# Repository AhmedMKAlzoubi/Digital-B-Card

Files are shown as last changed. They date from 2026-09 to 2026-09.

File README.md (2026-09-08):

# Digital Business Card (Digital-B-Card)

An ESP32-C3 based digital business card / badge with an e-paper display and NFC tap-to-share, designed as a custom PCB in a compact card/badge form factor.

## Overview

This project is a self-contained electronic business card. It combines a low-power microcontroller, an e-paper display for a persistent, battery-friendly visual, and an NFC tag for one-tap contact sharing on any NFC-enabled phone. The board is designed to fit inside a 3D-printed badge enclosure.

## Key Features

- **MCU:** ESP32-C3-MINI-1-N4 (RISC-V, Wi-Fi / BLE, native USB) for control logic and OTA wireless updates.
- **Display:** 2.66" e-paper panel (GDEM0266T71WT) driven by the SSD1680 controller — ultra-low power, always-on readability.
- **NFC:** NXP NT3H2111 NTAG I²C tag + custom 8-turn PCB antenna for tap-to-share contact info with any NFC-enabled phone.
- **Power:** MCP73871-2CC power-path LiPo charger + MAX17048 fuel gauge + AP2112K-3.3 LDO — USB-C charging with seamless battery monitoring.
- **Custom PCB:** Designed in KiCad, fabricated as a 2-layer, single-sided 100 × 60 mm board.
- **Custom Case:** 3D-modeled badge enclosure (FreeCAD) with an optional 3D nameplate.

## Repository Structure

| Folder / File | Description |
|---|---|
| `PCB-Schem/` | KiCad schematic (`.kicad_sch`) and PCB layout (`.kicad_pcb`) source files. |
| `Gerber/` | Fabrication-ready Gerber files, drill files, job file, and `gerber.7z` for direct upload to a PCB manufacturer. |
| `BOM/` | Bill of materials (`digital card-BOM.csv`). |
| `datasheets/` | Component datasheets and reference documents (see [Datasheets & Spec Sheets](#datasheets--spec-sheets) below). |
| `Case/` | FreeCAD badge case models (`Digital_Card_Case_3_BADGE.FCStd`), a backup revision, and a 3D nameplate (`case-nameplate.glb`). |
| `Digital_C-Case_Viewer.html` | Standalone browser-based 3D viewer for the case / nameplate model. |
| `DOC/` | Full project report (`Digital_Business_Card_Report.zip`) covering design decisions, testing, and build notes. |

---

## Specification Sheet

> Rev A — 2026-08-24. Values are marked **[V]** verified against a datasheet/layout/CAD, **[E]** estimated, or **[TBC]** to be confirmed on hardware.

### At a Glance

| Parameter | Value |
|---|---|
| Function | E-paper display with NFC tap-to-share and Wi-Fi / BLE connectivity |
| Modes | Desk nameplate / event badge / tap-to-share card (firmware-selected) |
| Outer dimensions | 104.6 × 69.6 × 11.1 mm **[V]** |
| Mass, assembled | ≈ 68 g **[E]** |
| Power | 1S Li-Po, USB-C rechargeable |
| Enclosure | Two-part 3D print, M2 screws |
| MCU | ESP32-C3-MINI-1-N4 (RISC-V, Wi-Fi + BLE, native USB) |
| Display | 2.66" e-paper, 152 × 296 px, SSD1680 driver (GDEM0266T71WT) |
| Connectivity | NFC (NT3H2111 + custom PCB antenna), Wi-Fi, BLE |
| Charging | USB-C, MCP73871-2CC power-path Li-Po charge management |
| Regulation | AP2112K-3.3 LDO |
| Fuel gauge | MAX17048 |
| Battery | 1S Li-Po, 500 mAh (Uxney 503035, 200–600 mAh range supported) |
| Design tool | KiCad |
| Manufacturing | JLCPCB, 2-layer, full SMT assembly |

### PCB Mechanical

| Parameter | Value |
|---|---|
| Outline | 100.0 × 60.0 mm **[V]** |
| Thickness | 1.6 mm **[V]** |
| Layers | 2 (F.Cu, B.Cu) **[V]** |
| Assembly | Single-sided — all components on B.Cu **[V]** |
| Mounting holes | 4 × Ø2.2 mm NPTH for M2, 2.75 mm from each corner **[V]** |
| Min track width | 0.25 mm signal / 0.40 mm power **[V]** |
| Min clearance | 0.20 mm (0.50 mm on HV class) **[V]** |
| Via / drill | 0.6 / 0.3 mm **[V]** |
| Surface finish | ENIG recommended |
| Placements | 59 across 27 orderable line items **[V]** |

### Enclosure

| Parameter | Value |
|---|---|
| Outer | 104.6 × 69.6 × 11.1 mm **[V]** |
| Wall / floor thickness | 2.0 mm **[V]** |
| PCB fit clearance | 0.3 mm per side **[V]** (may open to 0.4–0.5 mm **[TBC]**) |
| Split line | z = +1.6 mm — tray below, cover above **[V]** |
| Internal cavity | 100.6 × 65.6 × 5.5 mm deep **[V]** |
| Board support | 4 × Ø4.5 mm bosses with Ø1.7 mm pilot holes **[V]** |
| Fasteners | 4 × M2 self-tapping; nylon in the two holes nearest the NFC coil |
| USB-C opening | 12.6 × 6.2 mm **[V]** |
| Button access | 2 × Ø2.0 mm through tray floor **[V]** |

### Display

| Parameter | Value |
|---|---|
| Part | GDEM0266T71WT (Good Display) |
| Technology | E-paper, monochrome, bistable — zero power to hold image |
| Controller | SSD1680 (Solomon Systech) |
| Diagonal | 2.66" |
| Resolution | 152 × 296 px **[V]** |
| Active area | 30.704 × 60.088 mm **[V]** |
| Interface | 4-wire SPI, BS1 strapped low **[V]** |
| Connector | 24-pin 0.5 mm FPC, 14 mm tail **[V]** |
| Typical operating current | 4.5 mA **[V]** |
| Peak refresh current | 40 mA typ / 60 mA max **[V]** |

### Wireless

| Parameter | Value |
|---|---|
| MCU module | ESP32-C3-MINI-1-N4 (Espressif), RF pre-certified |
| Core | 32-bit RISC-V single core |
| Flash | 4 MB |
| Wi-Fi | 802.11 b/g/n, 2.4 GHz |
| Bluetooth | BLE 5 |
| Wi-Fi/BLE Antenna | Integrated module PCB antenna, overhanging board edge per Espressif guidance **[V]** |
| USB | Native USB (GPIO18/19) — programming and debug, no UART bridge |

### NFC

| Parameter | Value |
|---|---|
| Tag IC | NT3H2111W0FHKH (NXP NTAG I²C plus) |
| Standard | NFC Forum Type 2, 13.56 MHz |
| Host interface | I²C |
| Antenna | Custom PCB coil on F.Cu — 8 turns, 0.6 mm trace, 0.3 mm gap **[V]** |
| Coil area | 15 × 50 mm **[V]** |
| Coil inductance | ≈ 1.93 µH **[E]** |
| Chip capacitance | 50 pF **[V]** (datasheet §13.1) |
| Tuning capacitor | 22 pF C0G/NP0 **[V]** |
| Field-detect | FD → GPIO3, deep-sleep wake on tap **[V]** |
| Read range | **[TBC]** — C14 is the tuning point |

### Power

| Parameter | Value |
|---|---|
| Battery chemistry | Lithium polymer, 1 cell |
| Capacity | 500 mAh (200–600 mAh range supported) |
| Nominal / max voltage | 3.7 V / 4.2 V |
| Cell | Uxney 503035, 35 × 30 × 5 mm, integrated protection |
| Connector | JST-PH 2.0 mm, S2B-PH-SM4-TB horizontal SMT **[V]** |
| Regulation output | 3.3 V (AP2112K LDO, 600 mA rated) |
| LDO input source | Charger SYS/OUT rail — **not** VBAT |
| Charge IC | MCP73871-2CC, power-path topology |
| Charge voltage | 4.20 V **[V]** |
| Input current limit | 500 mA **[V]** |
| Charge current | ≈ 303 mA **[E]** |
| Termination current | ≈ 42 mA **[E]** |
| Safety timer | 6 h **[V]** |
| Worst-case dissipation | ≈ 0.4 W **[E]** |
| Fuel gauge | MAX17048, ModelGauge, 3 µA operating, I²C, ALRT → GPIO4 wake |

### Current Budget

| State | Estimate | Note |
|---|---|---|
| Deep sleep | ≈ 10–20 µA | MCU deep sleep + gauge 3 µA + leakage |
| Display holding image | 0 µA | Bistable — no power to retain |
| Display refresh | 40–60 mA for a few seconds | Panel datasheet §6.2 |
| Wi-Fi transmit | up to ≈ 350 mA peak | ESP32-C3 typical |
| NFC tap (harvested) | Field-powered | Tag responds without waking MCU |

### GPIO Pin Map

| GPIO | Net | Notes |
|---|---|---|
| 0 | I2C SDA | Shared bus — NFC + fuel gauge |
| 1 | I2C SCL | Shared bus |
| 2 | EPD RST | Strapping pin, 10 kΩ pull-up, idles high |
| 3 | NFC FD | Field detect; deep-sleep wake on tap (RTC-capable) |
| 4 | FUELGAUGE ALERT | MAX17048 ALRT; deep-sleep wake (RTC-capable) |
| 5 | EPD BUSY | Input |
| 6 | EPDCLK | E-paper SPI clock |
| 7 | EPDDATA | E-paper SPI data |
| 8 | STATUS LED | Strapping — must be high at boot, 10 kΩ pull-up |
| 9 | BOOT | Strapping, 10 kΩ pull-up + debounce cap, button to GND |
| 10 | EPD CS | E-paper chip select |
| 18 / 19 | USB D− / D+ | 0 Ω series to USB-C |
| 20 | EPD DC | Data/command |
| 21 | UART0 TX | Optional debug |
| EN | RESET | 10 kΩ pull-up + cap + RESET button |

### Manufacturing Summary

| Parameter | Value |
|---|---|
| Fabricator | JLCPCB |
| Process | 2-layer, full SMT assembly, single-sided |
| DRC | 0 violations, 12 documented exclusions **[V]** |
| ERC | Clean — one intentional informational note **[V]** |
| Gerber set | 9 files, Protel extensions, X2 attributes |
| BOM | 27 line items, 59 placements, LCSC part numbers on every row **[V]** |
| DNP | C5, C6 — USB ESD positions, deliberately unpopulated |
| Not in BOM | AE1 — antenna is etched copper |
| Enclosure | FDM, PLA, 2 parts, no supports required **[TBC]** |

---

## Bill of Materials (BOM)

The complete component list is in [`BOM/digital card-BOM.csv`](./BOM/digital%20card-BOM.csv). The table below is the authoritative human-readable BOM (27 orderable line items, 59 placements) with all LCSC part numbers.

> **Note:** C5 and C6 (USB ESD capacitor positions) are **DNP** (Do Not Populate). AE1 (NFC antenna) is etched copper — not a sourced component.

| Designator(s) | Value / Part | Package | LCSC # | Datasheet |
|---|---|---|---|---|
| U1 | ESP32-C3-MINI-1-N4 | Module | C2838502 | [esp32-c3-mini-1_datasheet_en.pdf](./datasheets/esp32-c3-mini-1_datasheet_en.pdf) |
| U2 | MAX17048G+T10 | TDFN-8 + EP | C2682616 | [C2682616.pdf](./datasheets/C2682616.pdf) |
| U3 | AP2112K-3.3 | SOT-23-5 | C51118 | [C51118.pdf](./datasheets/C51118.pdf) |
| U4 | NT3H2111W0FHKH | XQFN-8 | C710403 | [NT3H2111_2211.pdf](./datasheets/NT3H2111_2211.pdf) |
| U7 | MCP73871-2CC | QFN-20 + EP | C5121473 | [C5121473.pdf](./datasheets/C5121473.pdf) |
| J1 | USB-C TYPE-C-31-M-12 | 16P receptacle | C165948 | [C165948 (1).pdf](./datasheets/C165948%20(1).pdf) |
| J2 | JST S2B-PH-SM4-TB | PH 2.0 mm horiz. SMT | C295747 | [C295747.pdf](./datasheets/C295747.pdf) |
| J3 | AFC07-S24ECA-00 | 24P, 0.5 mm, top-contact | C262643 | [C262643 (2).pdf](./datasheets/C262643%20(2).pdf) |
| Q2 | SI1304BDL | SOT-323 | C7419947 | [C7419947 (1).pdf](./datasheets/C7419947%20(1).pdf) |
| L1 | 47 µH CDRH2D18 | SMD | C2454210 | [C2454210 (1).pdf](./datasheets/C2454210%20(1).pdf) |
| D1, D5, D6 | MBR0530 Schottky | SOD-123 | C77336 | [C77336 (1).pdf](./datasheets/C77336%20(1).pdf) |
| D2, D3, D4 | Red LED | 0603 | C2286 | [C2286.pdf](./datasheets/C2286.pdf) |
| SW1, SW2 | TS-1088-AR02016 tactile button | 4 × 3 mm SMD | C720477 | [C720477 (1).pdf](./datasheets/C720477%20(1).pdf) |
| R2, R3, R8, R9, R12, R17–R19 | 10 kΩ | 0805 | C17414 | [Uniroyal_resistors.pdf](./datasheets/Uniroyal_resistors%20(C17414%20C17521%20C22978%20C23179%20C23186%20C23352).pdf) |
| R1, R4, R5 | 0 Ω jumper | 0603 | C21189 | [Uniroyal_resistors.pdf](./datasheets/Uniroyal_resistors%20(C17414%20C17521%20C22978%20C23179%20C23186%20C23352).pdf) |
| R6, R7 | 5.1 kΩ (USB-C CC) | 0603 | C23186 | [Uniroyal_resistors.pdf](./datasheets/Uniroyal_resistors%20(C17414%20C17521%20C22978%20C23179%20C23186%20C23352).pdf) |
| R10 | 3.3 kΩ | 0603 | C22978 | [Uniroyal_resistors.pdf](./datasheets/Uniroyal_resistors%20(C17414%20C17521%20C22978%20C23179%20C23186%20C23352).pdf) |
| R11 | 24 kΩ | 0603 | C23352 | [Uniroyal_resistors.pdf](./datasheets/Uniroyal_resistors%20(C17414%20C17521%20C22978%20C23179%20C23186%20C23352).pdf) |
| R13, R14, R15 | 470 Ω | 0603 | C23179 | [Uniroyal_resistors.pdf](./datasheets/Uniroyal_resistors%20(C17414%20C17521%20C22978%20C23179%20C23186%20C23352).pdf) |
| R16 | 2.2 Ω sense resistor | 0805 | C17521 | [Uniroyal_resistors.pdf](./datasheets/Uniroyal_resistors%20(C17414%20C17521%20C22978%20C23179%20C23186%20C23352).pdf) |
| C1, C3, C8, C24 | 100 nF decoupling | 0805 | C28233 | [Samsung_MLCC_catalog.pdf](./datasheets/Samsung_MLCC_catalog%20(C1653%20C15849%20C19666%20C19702%20C21120%20C28233%20C28323).pdf) |
| C2, C11 | 10 µF bulk | 0603 | C19702 | [Samsung_MLCC_catalog.pdf](./datasheets/Samsung_MLCC_catalog%20(C1653%20C15849%20C19666%20C19702%20C21120%20C28233%20C28323).pdf) |
| C4, C9, C10, C18 | 1 µF 50 V X7R bypass | 0805 | C28323 | [Samsung_MLCC_catalog.pdf](./datasheets/Samsung_MLCC_catalog%20(C1653%20C15849%20C19666%20C19702%20C21120%20C28233%20C28323).pdf) |
| C7, C12 | 4.7 µF | 0603 | C19666 | [Samsung_MLCC_catalog.pdf](./datasheets/Samsung_MLCC_catalog%20(C1653%20C15849%20C19666%20C19702%20C21120%20C28233%20C28323).pdf) |
| C13 | 220 nF | 0603 | C21120 | [Samsung_MLCC_catalog.pdf](./datasheets/Samsung_MLCC_catalog%20(C1653%20C15849%20C19666%20C19702%20C21120%20C28233%20C28323).pdf) |
| C14 | 22 pF C0G/NP0 (NFC tuning) | 0603 | C1653 | [Samsung_MLCC_catalog.pdf](./datasheets/Samsung_MLCC_catalog%20(C1653%20C15849%20C19666%20C19702%20C21120%20C28233%20C28323).pdf) |
| C15–C17, C19–C23 | 1 µF 50 V X5R bypass | 0603 | C15849 | [Samsung_MLCC_catalog.pdf](./datasheets/Samsung_MLCC_catalog%20(C1653%20C15849%20C19666%20C19702%20C21120%20C28233%20C28323).pdf) |
| C5, C6 | **DNP** — USB ESD positions | 0603 | — | — |
| AE1 | NFC coil (etched copper, 8T) | — | — | — |

> **Total:** 27 orderable line items / 59 placements. Raw CSV: [`BOM/digital card-BOM.csv`](./BOM/digital%20card-BOM.csv)

---

## Datasheets & Spec Sheets

All component datasheets are in the [`datasheets/`](./datasheets) directory. A single combined quick-reference is also available at [`datasheets/all_datasheets_combined.md`](./datasheets/all_datasheets_combined.md).

### ICs & Active Components

| Component | LCSC # | Description | Datasheet |
|---|---|---|---|
| ESP32-C3-MINI-1-N4 | C2838502 | RISC-V SoC module, Wi-Fi + BLE, native USB | [esp32-c3-mini-1_datasheet_en.pdf](./datasheets/esp32-c3-mini-1_datasheet_en.pdf) |
| ESP32-C3 HW Guidelines | — | PCB layout and antenna design guide | [esp-hardware-design-guidelines-en-master-esp32c3.pdf](./datasheets/esp-hardware-design-guidelines-en-master-esp32c3.pdf) |
| SSD1680 | — | E-paper display controller | [SSD1680.pdf](./datasheets/SSD1680.pdf) |
| GDEM0266T71WT | — | 2.66" e-paper panel | [GDEM0266T71WT.pdf](./datasheets/GDEM0266T71WT.pdf) |
| NT3H2111W0FHKH | C710403 | NXP NTAG I²C NFC tag | [NT3H2111_2211.pdf](./datasheets/NT3H2111_2211.pdf) |
| MAX17048G+T10 | C2682616 | 1–2 cell fuel gauge (I²C, ModelGauge) | [C2682616.pdf](./datasheets/C2682616.pdf) |
| AP2112K-3.3 | C51118 | 600 mA LDO regulator | [C51118.pdf](./datasheets/C51118.pdf) |
| MCP73871-2CC | C5121473 | LiPo power-path charge management | [C5121473.pdf](./datasheets/C5121473.pdf) |
| SI1304BDL (Q2) | C7419947 | N-MOSFET, boost converter switch | [C7419947 (1).pdf](./datasheets/C7419947%20(1).pdf) |

### Passive & Discrete Components (LCSC)

| LCSC # | Component | Designator(s) | File |
|---|---|---|---|
| C165948 | USB Type-C receptacle | J1 | [C165948 (1).pdf](./datasheets/C165948%20(1).pdf) |
| C295747 | JST S2B-PH-SM4-TB battery connector | J2 | [C295747.pdf](./datasheets/C295747.pdf) |
| C262643 | AFC07-S24ECA-00 FPC connector | J3 | [C262643 (2).pdf](./datasheets/C262643%20(2).pdf) |
| C2454210 | 47 µH CDRH2D18 inductor | L1 | [C2454210 (1).pdf](./datasheets/C2454210%20(1).pdf) |
| C77336 | MBR0530 Schottky diode | D1, D5, D6 | [C77336 (1).pdf](./datasheets/C77336%20(1).pdf) |
| C2286 | Red LED 0603 | D2, D3, D4 | [C2286.pdf](./datasheets/C2286.pdf) |
| C720477 | TS-1088-AR02016 tactile button | SW1, SW2 | [C720477 (1).pdf](./datasheets/C720477%20(1).pdf) |

### Catalog References

| Catalog | Covers (LCSC #s) | File |
|---|---|---|
| Samsung MLCC | C1653, C15849, C19666, C19702, C21120, C28233, C28323 | [Samsung_MLCC_catalog.pdf](./datasheets/Samsung_MLCC_catalog%20(C1653%20C15849%20C19666%20C19702%20C21120%20C28233%20C28323).pdf) |
| Uniroyal Resistors | C17414, C17521, C22978, C23179, C23186, C23352 | [Uniroyal_resistors.pdf](./datasheets/Uniroyal_resistors%20(C17414%20C17521%20C22978%20C23179%20C23186%20C23352).pdf) |

---

## Documentation

The full project report — covering design rationale, schematic/PCB walkthrough, assembly notes, and testing — is available in [`DOC/Digital_Business_Card_Report.zip`](./DOC/Digital_Business_Card_Report.zip).

---

## Manufacturing

To fabricate the PCB, upload [`Gerber/gerber.7z`](./Gerber/gerber.7z) (or the individual Gerber/drill files) to JLCPCB or your PCB manufacturer of choice with full SMT assembly. Reference the [BOM table](#bill-of-materials-bom) above or the CSV for component sourcing.

**Pre-order checklist:**
- Verify polarized-part orientations (Q2, U7, U2, U4, diodes, LEDs) in the JLCPCB assembly preview.
- Confirm BOM excludes DNP rows (C5/C6) and the etched antenna (AE1).
- Use nylon (not steel) M2 screws in the two mounting holes nearest the NFC coil.
- On battery arrival: verify lead polarity at J2 with a multimeter before first connection — JST-PH polarity is not standardized.

---

## Case & Enclosure

The badge enclosure is modeled in FreeCAD (`Case/Digital_Card_Case_3_BADGE.FCStd`). A 3D nameplate model (`case-nameplate.glb`) can be previewed directly in a browser using [`Digital_C-Case_Viewer.html`](./Digital_C-Case_Viewer.html).

---

## License

N/A

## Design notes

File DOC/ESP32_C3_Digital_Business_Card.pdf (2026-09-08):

## ESP32-C3 Digital Business Card

A rechargeable, NFC-enabled e-paper business card — designed from a blank schematic sheet to a manufacturable PCB

Ahmed Mohammed Khear

2026

Abstract
This document records the complete hardware design of a digital business card built around the ESP32-C3: a 100 × 60 mm, two-layer PCB combining an always-on e-paper display, an NFC tap-to-share interface with a custom-tuned PCB antenna, and USB-C rechargeable Li-Po power. It was designed by hand in KiCad as both a portfolio piece and a cost-competitive alternative to commercial NFC cards. Beyond the final design, this document preserves the reasoning: every major component choice traces to a named datasheet section, and the places where the design deliberately deviates from a datasheet’s typical application are explained in full, so the trade-offs remain understandable to both an experienced reviewer and my future self.

## Contents

1 Introduction | 3
2 System Overview | 3
3 Background Concepts | 5
4 Component Selection | 6
5 Detailed Design | 6
6 PCB Layout | 13
7 Verification and Design Review | 15

8 Manufacturing | 15
9 Firmware Notes and Future Work | 16
Acknowledgements | 16
A Toolchain and Library Setup | 16
B Specification Sheet | 17
C Full Bill of Materials | 23
D References | 23

## 1 Introduction

The idea: a business card you never throw away. A phone tapped against the card receives a resume or website link over NFC; an e-paper panel shows a QR code, the date, and phoneset reminders while consuming nothing to hold the image; a small Li-Po recharges over USB-C. Commercial NFC cards sell upward of $70 with far less functionality, which made this an attractive target for a fully custom board.
Working method. The schematic and layout were built by hand in KiCad, with Claude (Anthropic’s AI assistant) working alongside as senior-engineer reviewer, design-audit partner, and co-author of the project tooling and this document (see the Acknowledgements). Two disciplines were enforced throughout and shaped this document:
- Every design decision traces to a named datasheet or specification section — never to a vendor summary or an unverified claim.
- Everything is verified against primary sources; several plausible-sounding review suggestions were rejected precisely because the primary source said otherwise (Section 7).
Parts are sourced on JLCPCB/LCSC with an LCSC field on every schematic symbol, targeting JLCPCB fabrication with full SMT assembly.

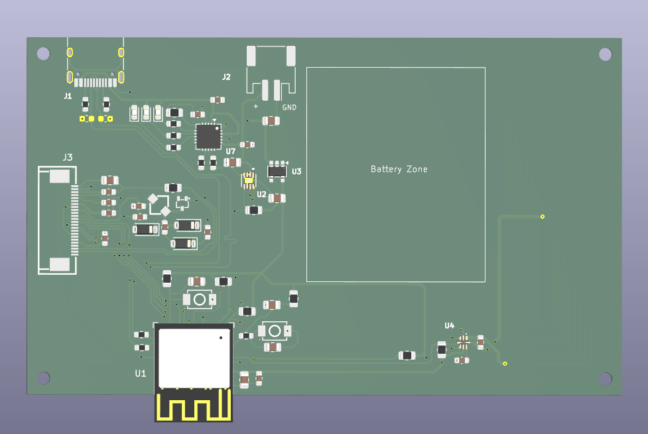
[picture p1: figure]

Figure 1: 3D render of the fully populated board (component side), showing the ESP32-C3 module with its antenna overhanging the board edge, the USB-C connector, the e-paper FPC connector (J3), the battery zone, and the charging and power-management cluster.

## 2 System Overview

### 2.1 Specifications

### 2.2 Power architecture

The device spends most of its life in deep sleep with short active bursts (hourly display refresh, NFC taps, BLE sessions) — this duty cycle is what drives the e-paper-centric, low-power archi-

Spec | Value
Board | 100 × 60 mm, 2-layer, single-sided assembly
MCU | ESP32-C3-MINI-1-N4 (RISC-V, Wi-Fi + BLE, native USB)
Display | 2.66” e-paper, 152×296 px, SSD1680 driver (GDEM0266T71WT)
Connectivity | NFC (NT3H2111 + custom PCB antenna), Wi-Fi, BLE
Charging | USB-C, MCP73871-2CC power-path Li-Po charge management
Regulation | AP2112K-3.3 LDO
Fuel gauge | MAX17048
Battery | 1S Li-Po, 200 mA h to 600 mA h (Uxney 503035, 500 mA h selected)
Design tool | KiCad
Manufacturing | JLCPCB, 2-layer, full SMT assembly

Table 1: Headline specifications.

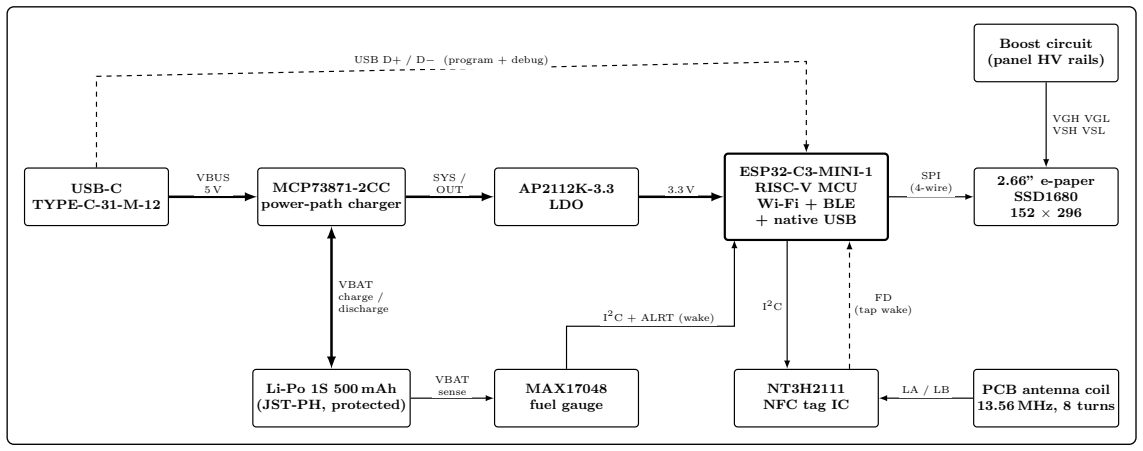
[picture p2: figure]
USB-C TYPE-C-31-M-12; MCP73871-2CC power-path charger; AP2112K-3.3 LDO; ESP32-C3-MINI-1 RISC-V MCU Wi-Fi + BLE; + native USB; 2.66” e-paper SSD1680 152 × 296; Boost circuit (panel HV rails); Li-Po 1S 500 mAh (JST-PH, protected); MAX17048 fuel gauge; NT3H2111 NFC tag IC; PCB antenna coil 13.56 MHz, 8 turns; VBUS 5 V; SYS /; OUT; VBAT charge / discharge; VBAT sense; USB D+ / D− (program + debug); SPI (4-wire); VGH VGL VSH VSL; FD (tap wake); 2C + ALRT (wake)

Figure 2: System block diagram. Thick lines carry power; thin lines are digital interfaces; dashed lines are the two deep-sleep wake paths and the USB programming link. The charger’s SYS/OUT rail — not the battery terminal — feeds the LDO, which is what makes the power path seamless.

tecture. Mechanically the card is serviceable: a 3D-printed case that opens, with a replaceable JST-PH battery.

## 3 Background Concepts

The concepts below are used throughout the rest of the document. An experienced reader can skip this section entirely; each later section points back here where a concept first matters.

What is a power-path charger?

A simple charger IC charges the battery, and the system then runs from the battery — meaning a dead battery makes the device unusable even when plugged in, and system current confuses the charge-termination logic. A power-path charger like the MCP73871 separates the two: the system rail (SYS/OUT) is powered directly from USB when present and switches seamlessly to the battery otherwise, while the battery charges independently. This is why the LDO’s input is the charger’s OUT pin, not the battery terminal.

What is a strapping pin?

Some GPIOs are read at the moment of reset to configure how the chip boots (normal flash boot vs. download mode, etc.). On the ESP32-C3 these are GPIO2, GPIO8 and GPIO9. If external circuitry pulls one of these the wrong way at power-up, the chip silently boots into the wrong mode. Every strapping pin in this design carries a pull-up that both satisfies boot requirements and serves the attached peripheral (e.g. GPIO2’s pull-up doubles as the e-paper reset idle-high).

What is the 5.1 k CC pull-downs on USB-C?

A USB-C source decides how much current to offer by measuring the CC pins. A device that wants power (a “sink”) must present 5.1 kΩ on both CC lines — without them, a USB-C-to-USB-C cable delivers no VBUS at all and the board would mysteriously only charge from A-to-C cables.

What is a DNP (Do Not Populate) part — and why the USB ESD caps are DNP?

DNP means the footprint exists on the board but no part is fitted at assembly: the position is a free option for later. Here, C5/C6 are small capacitor positions on the USB data lines, reserved for ESD/filtering. They are left unpopulated because extra capacitance on USB data lines degrades signal edges, and the ESP32-C3’s internal protection is adequate for a personal device — but the pads cost nothing, so a future revision (e.g. a sale version adding proper TVS diodes) can populate them without a board respin. DNP positions must be excluded when exporting the BOM, or the assembler will try to source a part literally valued “C”.

What is a 0 Ω resistor?

A resistor with (nominally) zero resistance — electrically just a wire, so why fit one? Because it is a removable, replaceable wire: it provides a break point to isolate a circuit section during debugging (desolder one part instead of cutting copper), and a substitution point if a small series resistance or ferrite bead turns out to be needed later. In this design, 0 Ω resistors sit in series with the USB D+/D− lines, placed symmetrically on the pair so both data lines see identical parasitics.

What is ceramic capacitor dielectrics (C0G vs. X5R/X7R) and DC bias?

Ceramic capacitors trade size for stability. X5R/X7R dielectrics lose a large fraction of their capacitance as DC voltage is applied across them (“DC bias”) and drift with temperature — fine for decoupling, fatal for a resonant circuit, where drifting capacitance detunes an antenna away from its frequency. C0G/NP0 dielectric is nearly ideal (no bias effect, tiny tempco), which is why the NFC tuning capacitor is specified as C0G despite costing more per microfarad. The same physics appears at the e-paper VCOM capacitor, where an X7R part is chosen with enough voltage headroom that its biased capacitance still meets the requirement (Section 5.6).

## 4 Component Selection

Function | Part | LCSC | Package
MCU | ESP32-C3-MINI-1-N4 | C2838502 | module
Charger | MCP73871-2CC | C5121473 | QFN-20 4×4 + EP
Fuel gauge | MAX17048G+T10 | C2682616 | TDFN-8 2×2 + EP
LDO | AP2112K-3.3 | C51118 | SOT-23-5
NFC | NT3H2111W0FHKH | C710403 | XQFN-8
USB-C | HRO TYPE-C-31-M-12 | C165948 | 16-pin receptacle
FPC connector | AFC07-S24ECA-00 (top contact) | C262643 | 24P, 0.5 mm
Battery conn. | JST S2B-PH-SM4-TB | C295747 | PH 2.0 mm, horiz. SMT
Boost NMOS | SI1304BDL | C7419947 | SOT-323
Boost inductor | CDRH2D18, 47 µH | C2454210 | SMD
Schottky ×3 | MBR0530 | C77336 | SOD-123
Buttons ×2 | TS-1088-AR02016 | C720477 | 4×3 mm tactile

Table 2: Principal components. The full BOM including all passives is in Appendix C.

Why these parts, briefly:
- ESP32-C3-MINI-1: integrated PCB antenna (RF pre-certified, no RF layout risk), native USB for programming and debug with no UART bridge chip, RISC-V core, deep-sleep in the microamp range.
- MCP73871-2CC: true power-path management (see explainer above). The -2CC suffix specifically encodes 4.20 V regulation, a 6-hour safety timer, and a 3.1 V low-battery threshold — the suffix table on the datasheet’s Product Identification page is the only place these differ between variants.
- MAX17048: battery percentage without a sense resistor (ModelGauge), 3 µA operating current, I²C, and an ALRT pin used as a deep-sleep wake source.
- NT3H2111: NFC Forum Type 2 tag with an I²C host interface, energy harvesting, and a field-detect output that wakes the ESP32 from deep sleep on a phone tap.
- SSD1680 panel (GDEM0266T71WT): holds its image at zero power; only refreshes cost energy.

## 5 Detailed Design

The complete schematic is shown in Figure 3; the subsections below walk through each block and the reasoning behind it.

### 5.1 MCU: pin map and strapping

The module symbol/footprint come from Espressif’s official KiCad library (https://github.com/espressif/kicad-libraries); (https://github.com/espressif/kicad-libraries) power, enable and reset networks follow the ESP32-C3-MINI-1 datasheet’s Peripheral Schematics section (Espressif recommends R = 10 kΩ and C = 1 µF on EN). Strapping pins — and why they shape this pin map — are explained in Section 3.

Design decision: wake pins must be RTC-capable

Only GPIO0–GPIO5 can wake the ESP32-C3 from deep sleep. Both wake sources were deliberately placed in that range: GPIO3 (NFC field detect — a phone tap wakes the card) and GPIO4 (fuel-gauge alert — a low battery wakes the card to warn the user).

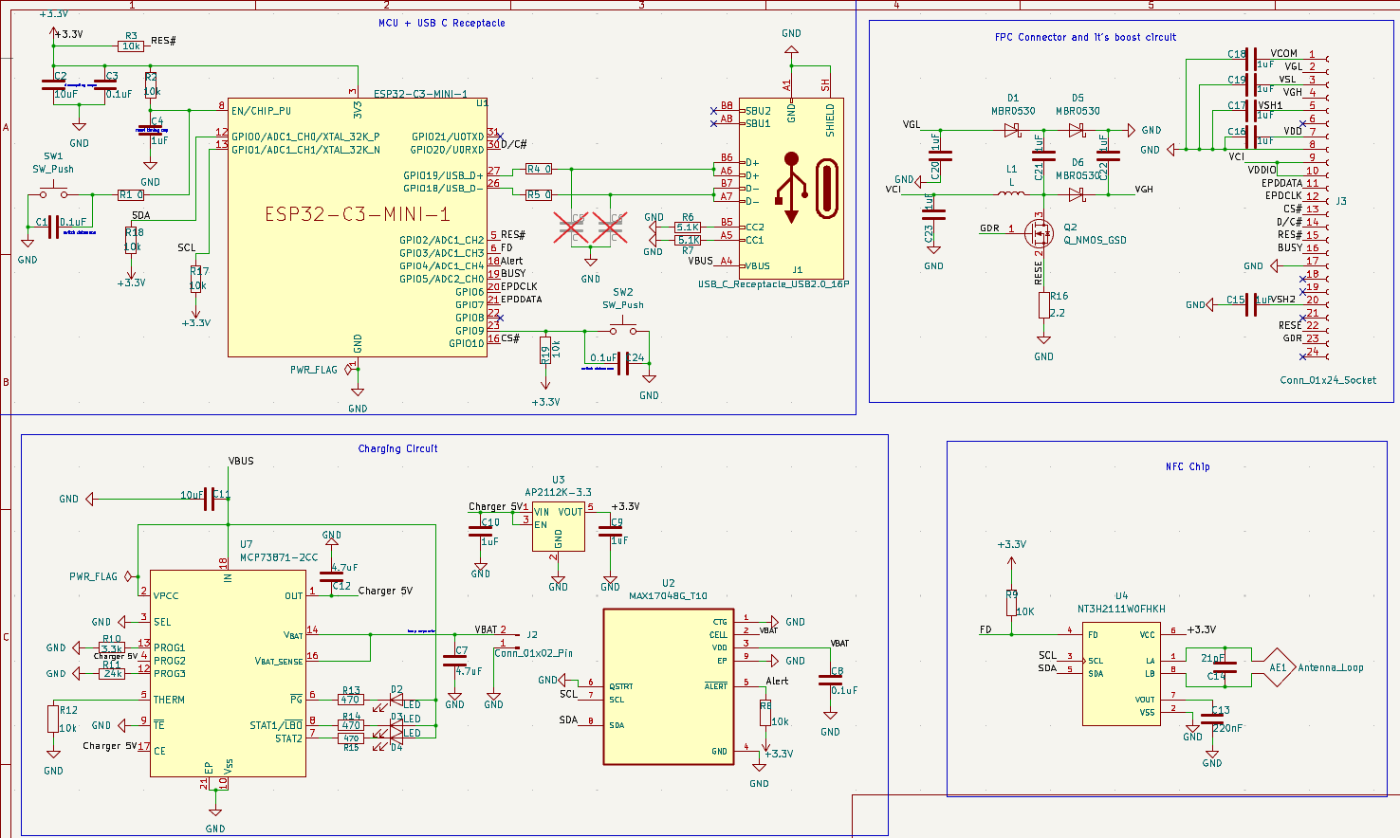
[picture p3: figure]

Figure 3: Complete schematic, drawn as four functional blocks: the MCU with its USB-C receptacle (top left), the e-paper FPC connector with its boost circuit (top right), the charging circuit with the LDO and fuel gauge (bottom left), and the NFC front end with its antenna (bottom right).

GPIO | Net | Notes
0 | I2C SDA | shared bus (NFC + fuel gauge)
1 | I2C SCL | shared bus
2 | EPD RST | strapping pin → 10k pull-up, idles high
3 | NFC FD | field detect; deep-sleep wake on tap (RTC-capable)
4 | FUELGAUGE ALERT | MAX17048 ALRT; deep-sleep wake (RTC-capable)
5 | EPD BUSY | input
6 | EPDCLK | e-paper SPI clock
7 | EPDDATA | e-paper SPI data
8 | STATUS LED | strapping → must be high at boot, 10k pull-up
9 | BOOT button | strapping, 10k pull-up + debounce cap, button to GND
10 | EPD CS | e-paper chip select
18/19 | USB D−/D+ | 0 Ω series to USB-C
20 | EPD DC | data/command
21 | UART0 TX | optional debug
EN | RESET | 10k pull-up + cap + RESET button

Table 3: Boot-safe pin map.

Design decision: renaming the e-paper SPI nets

The panel’s datasheet labels its SPI pins “SCL/SDA” — the same names as the I²C bus, which invites miswiring. The nets were renamed EPDCLK/EPDDATA so the two buses cannot be confused anywhere in the schematic.

### 5.2 USB-C

HRO TYPE-C-31-M-12 receptacle (USB 2.0, 16-pin). D± route through 0 Ω series resistors to GPIO19/18 (the resistors are debug/isolation points placed symmetrically on the pair); CC1/CC2 each carry a 5.1 kΩ pull-down to ground; data-line ESD capacitor positions exist but are DNP. Why the CC pull-downs are essential, why the ESD positions are deliberately unpopulated, and what the 0 Ω resistors are for are all covered in Section 3.
The footprint was verified dimension-by-dimension against the connector’s mechanical drawing: mounting-hole spacing 5.78 mm, X-axis pitch 8.9 mm exact, Y placement within the ±0.05 mm drawing tolerance (PCB 7.3 mm vs drawing 7.35 mm), and all pads (4×0.6 mm, 8×0.3 mm) matching in size, naming and numbering.

### 5.3 Battery charger: MCP73871-2CC

Every configuration strap traces to a datasheet section:

Pin | Strap | Effect (datasheet ref)
SEL | GND | USB mode (§3.4, §5.2.2)
PROG2 | OUT | 500 mA input limit (§3.9)
PROG1 | 3.3 kΩ to VSS | ≈303 mA charge current (Eq. 5-1)
PROG3 | 24 kΩ to VSS | ≈42 mA termination (Eq. 4-2)
THERM | fixed 10 kΩ to VSS | see below (§5.1.4)
CE | OUT | charge enabled, never floating (§3.16)
TE | GND | 6-hour safety timer on
VPCC | IN | disabled; input current limit already caps at 500 mA (§3.3)

Table 4: MCP73871 strap configuration.

Design decision: no thermistor — a fixed 10 k on THERM

The MCP73871 expects the battery pack to contain an NTC thermistor (a resistor whose value changes with temperature) wired to its THERM pin. The charger pushes a fixed 50 µA out of that pin and measures the voltage that appears; by Ohm’s law (V = I × R) the voltage reveals the thermistor’s resistance, and therefore the battery’s temperature. A reading above 1.24 V means “resistance high → battery too cold”; below 0.25 V means “resistance low → battery too hot” — and the charger pauses charging either way.
This design’s battery is a small protected Li-Po with no thermistor wire available, so THERM instead gets a fixed 10 kΩ to VSS: 50 µA × 10 kΩ = 0.5 V, permanently in the middle of the safe window. The charger is deliberately made to always believe the battery is at a comfortable temperature, and temperature safety is knowingly delegated to the protection circuit built into the battery pack itself. Two traps live here, and both nearly happened:
- Grounding THERM reads 0 V — below the hot threshold, so the charger suspends charging permanently. The intuitive “tie the unused pin low” instinct produces a board that never charges.
- The wrong resistor value does the same. A BOM error (caught in a pre-order audit) had assigned the 3.3 kΩ part here: 50 µA × 3.3 kΩ = 0.165 V — also read as “too hot,” also a card that never charges. The margin analysis above is the whole point of the 10 kΩ value.

Status LEDs (STAT1/STAT2/PG) each drive an LED + 470 Ω pulled to VBUS — PG must be referenced to the input rail per §5.2.4, and pulling to VBUS means the LEDs only light when

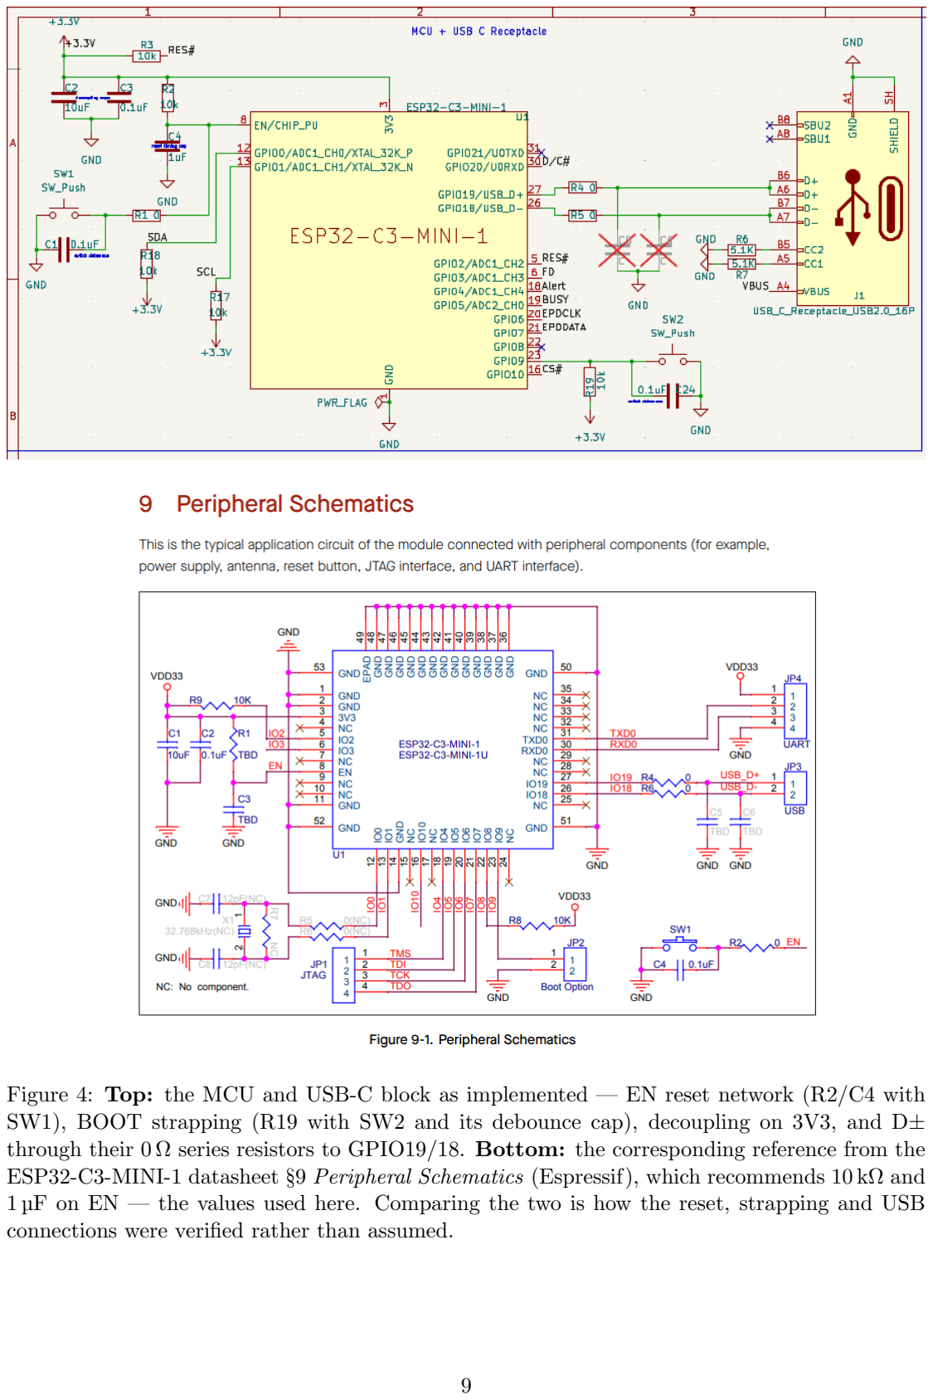
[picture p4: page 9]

Figure 4: Top: the MCU and USB-C block as implemented — EN reset network (R2/C4 with SW1), BOOT strapping (R19 with SW2 and its debounce cap), decoupling on 3V3, and D± through their 0 Ω series resistors to GPIO19/18. Bottom: the corresponding reference from the ESP32-C3-MINI-1 datasheet §9 Peripheral Schematics (Espressif), which recommends 10 kΩ and 1 µF on EN — the values used here. Comparing the two is how the reset, strapping and USB connections were verified rather than assumed.

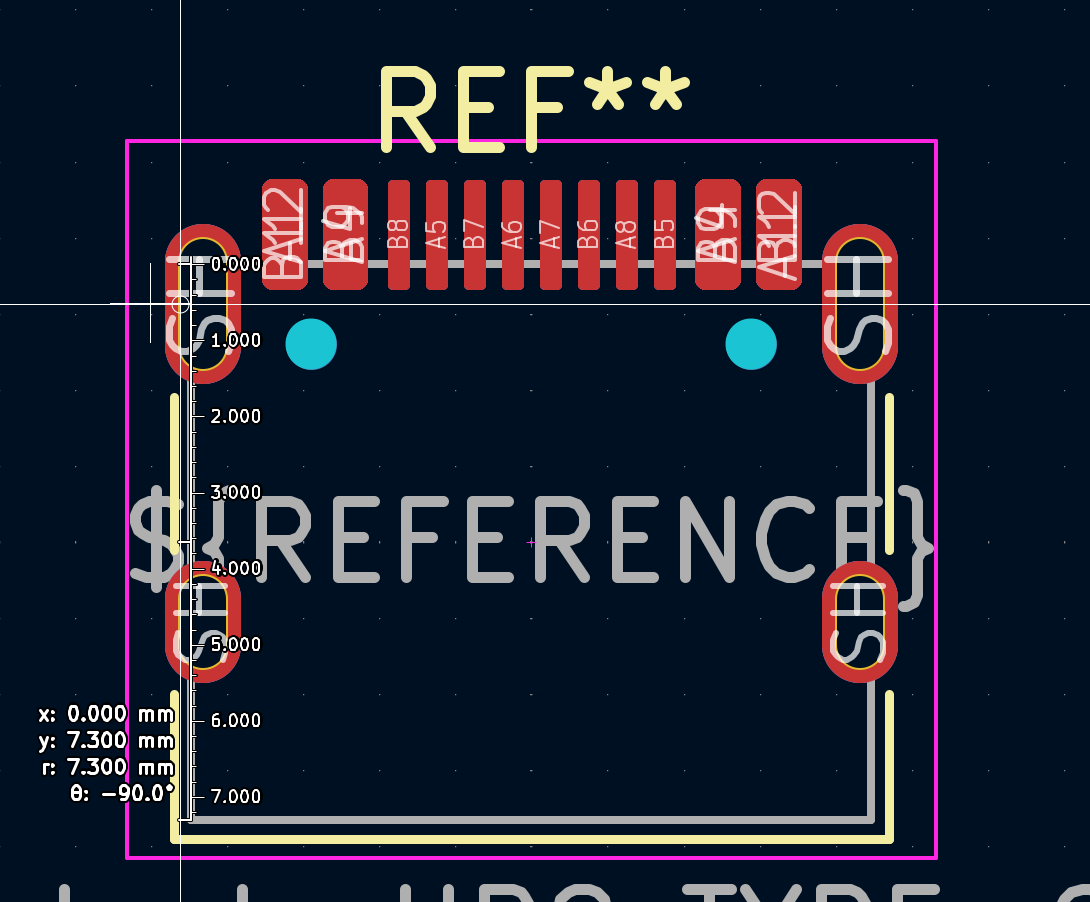
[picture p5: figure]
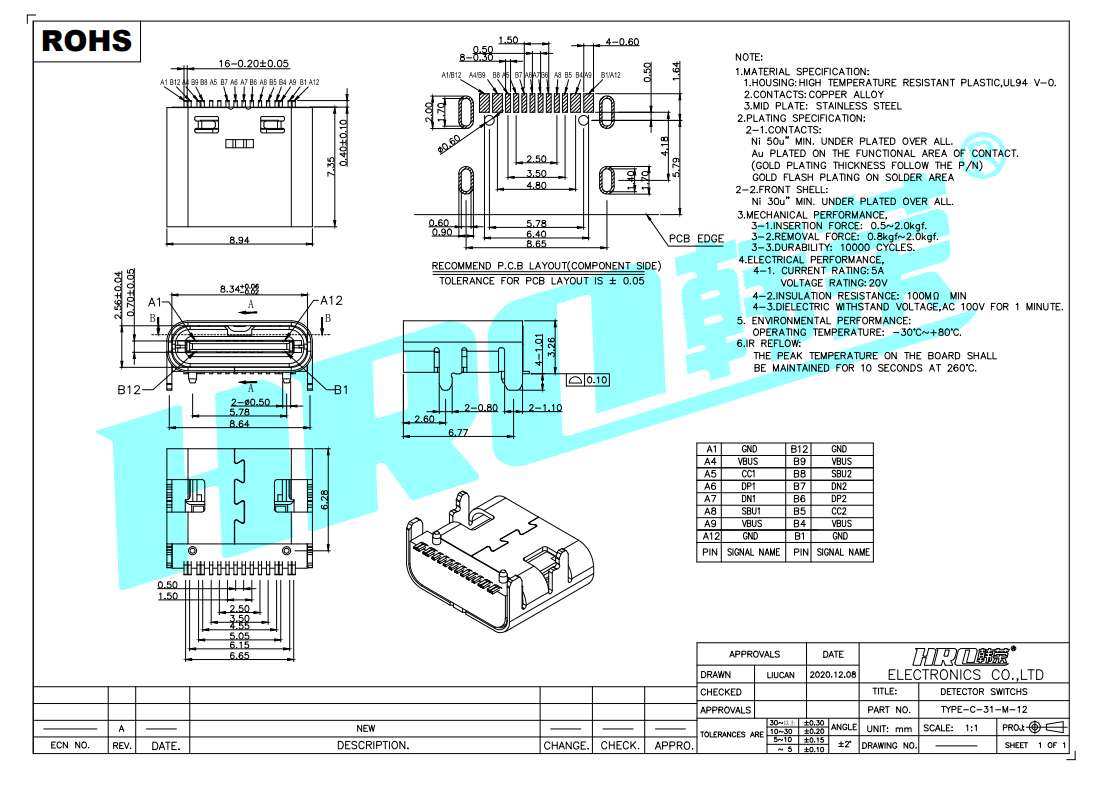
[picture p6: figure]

Figure 5: Top: the KiCad footprint measured with the built-in measure tool — the readout shows 7.300 mm between the mounting-hole rows. Bottom: the corresponding TYPE-C-31-M-12 mechanical drawing (HRO Electronics), whose Recommended PCB Layout gives 7.35 mm with a ±0.05 mm layout tolerance, along with the 5.78 mm and 8.94 mm references and the 4×0.6 mm / 8×0.3 mm pad sizes. Each dimension, pad size and pin name was checked against the drawing before the connector was placed — a library footprint being “the right part name” is not the same as it matching the part you ordered. 10

USB is present, saving battery. The exposed pad ties to GND with thermal vias (the charger dissipates roughly 0.4W worst-case).

### 5.4 Regulator and fuel gauge

AP2112K-3.3 (SOT-23-5): input from the charger’s SYS/OUT rail — not VBAT, which is the entire point of the power-path architecture — EN tied to VIN, 1 µF in and out.
MAX17048 (TDFN-8): VDD and CELL both connect to VBAT, because VDD is simultaneously the supply and the sense input — powering it from 3.3 V would make it measure the regulator instead of the battery. QSTRT/CTG and the exposed pad go to GND; ALRT goes to GPIO4 as a wake source.

### 5.5 NFC front end and antenna

The NT3H2111 (XQFN-8, no exposed pad) connects to the shared I²C bus; FD goes to GPIO3 with a pull-up; a 220 nF capacitor sits on VOUT. The antenna connects across LA/LB with the tuning capacitor in parallel, forming the resonant tank of NXP AN11276’s equivalent-circuit model.

### 5.5.1 Antenna design

The antenna is not a component — it is a rectangular planar spiral etched directly into the front copper. The design constants:
- Resonance target: 13.56 MHz (NFC standard)
- Chip internal capacitance: Ci = 50 pF (NT3H2111 datasheet §13.1)
- Available area: 15 × 50 mm strip on the card’s right edge
From the resonance equation

f =

1
2π

√
LC

⇒ Lideal =

1
(2πf)

2Ci

≈ 2.755 µH

if the chip’s capacitance alone were to resonate the coil. The final geometry (iterated in ST’s eDesign coil tool and cross-checked with an independent Greenhouse-model calculation):

Outer footprint | ∼15 × 50 mm
Turns | 8
Trace width / spacing | 0.6 mm / 0.3 mm
Resulting inductance | ≈1.93 µH
Total capacitance for resonance | ≈71 pF
External tuning cap C14 | 22 pF C0G/NP0 (LCSC C1653)

Table 5: Final antenna geometry.

Design decision: 8 turns at 0.3 mm spacing, not 6 at 0.6 mm

An earlier 6-turn variant (≈1.15 µH) would have needed ∼70 pF of external capacitance. Tightening the spacing to 0.3 mm fits 8 turns in the same strip, raising inductance so only ∼21 pF external is needed. More of the resonance comes from the coil itself: higher Q, better read range, and less sensitivity to the tuning cap’s tolerance.

The design intentionally sits slightly high in frequency to absorb real-world detuning from nearby metal and the ground pour, and C14 remains an accessible tuning position for bench adjustment (VNA or simple read-range testing) after assembly — C0G dielectric is mandatory in this position (Section 3). The antenna strip is kept clear of copper on both faces, and the battery is deliberately placed away from it — a large conductive object behind the coil would shield and detune it. Because 8 turns leave only a small inner aperture, the inner terminal exits through a via and a single thin bridge on the back copper (a thin bridge is acceptable inside the keep-out; a pour is not).

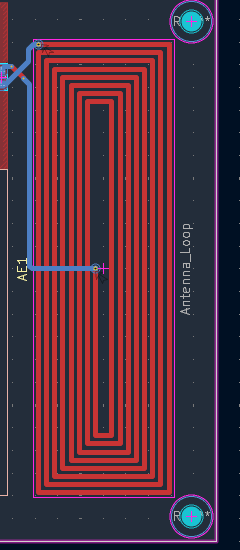
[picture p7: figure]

Figure 6: The NFC coil as etched copper in the right-hand strip: 8 rectangular turns at 0.6 mm width and 0.3 mm spacing, with the inner terminal exiting through a via. The surrounding area is kept clear of copper on both layers so the coil couples cleanly to a phone.

### 5.6 E-paper interface and boost converter

The SSD1680 controller drives the panel over 4-wire SPI (BS1 strapped to GND selects this mode, datasheet §6.3.1) and generates its own high-voltage gate/source/VCOM rails from an external boost circuit, wired one-to-one from the panel vendor’s reference application circuit (GDEM0266T71WT §9): NMOS SI1304BDL, 47 µH CDRH2D18 inductor, three MBR0530 Schottkys, 2.2 Ω sense resistor, 1 µF rail capacitors, and the VCOM capacitor.
Four verification stories from this block are worth preserving:

Design decision: the MOSFET pinout that ERC cannot catch

The generic KiCad NMOS symbol first used had pin order Drain–Gate–Source; the SI1304BDL is Gate–Source–Drain. Every pin was mismatched — a dead boost converter with zero ERC warnings, because electrically the netlist was “valid.” Caught only by checking the symbol pin numbers against the datasheet package drawing; fixed by switching to the Q NMOS GSD symbol variant and re-verifying all three connections. Symbol-to-package pin mapping is a class of error only datasheet review catches.

Design decision: keeping the reference 47 uH inductor (review challenge rejected)

A review pass claimed the SSD1680 boost “requires 10 µH” and that the reference part’s 200 mA saturation rating would be exceeded. The panel’s own datasheet settled it: §9 explicitly lists CDRH2D18 47 µH as the reference part, and §6.2 gives actual panel current as 4.5 mA typical operating / 40 mA typical peak — 3–5× below saturation even in the strictest reading. The challenge was specific and plausible, but generic; the primary source won. (Documented fallback: a higher-Isat 47 µH part if rails measure low on the bench.)

Design decision: Rds(on) at the gate drive that actually exists

The SI1304BDL’s headline 450 mΩ is specified at VGS = 4.5 V — a voltage this circuit never reaches. The applicable figure is 0.65 Ω max at VGS = 2.5 V, still comfortably under the reference’s ≤2.1 Ω requirement. Always read the test conditions column.

Design decision: the VCOM capacitor and DC bias

The reference calls for an effective capacitance >0.25 µF at 18 V DC bias in the VCOM position, X7R dielectric required. Verified via Samsung’s MLCC DC-bias data: the chosen 1 µF 50 V X7R part measures 0.89 µF at 18.4 V — roughly 3.5× the requirement. The generous voltage headroom (18 V on a 50 V part) is what preserves the capacitance; an X5R part of the same nominal value would not have qualified.

### 5.6.1 FPC connector: which side are the contacts on?

The panel’s 14 mm tail wraps around the board edge to a back-mounted connector, with the board inside the fold. The panel’s gold fingers are on the screen side — the outer face of the wrap — which stays outer all the way around, so at the connector they face away from the board: a top-contact connector (AFC07-S24ECA-00) is required. The bottom-contact sibling (S24FCA) differs by one letter and would make the panel physically unconnectable — a one-letter difference worth re-checking every time the BOM is regenerated.
Pin order also reverses through the wrap: connector pad P receives panel pin (25 − P). The layout was verified by matching signals (each panel signal landing on the pad carrying that net) rather than trusting pin numbers. BS lands on GND (4-wire SPI select), and VDDIO merges into VCI per the SSD1680 datasheet §5 Table 5-1 — the one intentional ERC informational note in the design.

## 6 PCB Layout

### 6.1 Floorplan and stack-up

Two layers, 100 × 60 mm. The X-axis budget sums exactly: 5 mm margin + 72 mm panel zone + 3 mm divider + 15 mm antenna strip + 5 mm margin = 100 mm.
- Front: e-paper panel (held a few millimetres off the board by the case) and the NFC coil in the right-hand strip.
- Back: all SMD components — keeping assembly single-sided, the cheapest option. The antenna is etched copper (free), and the two vias linking it to the NFC chip do not trigger double-sided assembly charges.
- Battery: on the back, behind the panel region — deliberately not behind the antenna. Staying 2-layer was a considered decision: every interface is low-speed (e-paper SPI, I²C, full-speed USB), so a 4-layer stack is not warranted, and only a routability wall would have changed that.

### 6.2 Grounding on a 2-layer board

There is no hidden plane on a 2-layer board. The ground strategy: components and their pours share the back copper (GND pads connect directly into the fill, no vias needed), while the front carries a large ground pour in the free area under the panel — stopping 3 mm short of the antenna strip. Vias to ground exist only where needed: front-copper returns, stitching, and the thermal arrays under the charger and fuel-gauge exposed pads.

### 6.3 Module antenna placement

The ESP32-C3-MINI-1 sits at the top edge with its PCB antenna overhanging the board by design: Espressif’s hardware design guidelines state the module antenna should be outside the base board with the feed point close to the edge — the preferred configuration for radiation performance, not a compromise. The module body remains fully seated (all 61 pads ≥1 mm inboard); only the antenna tail extends past, protected by a keep-out zone on both copper layers.

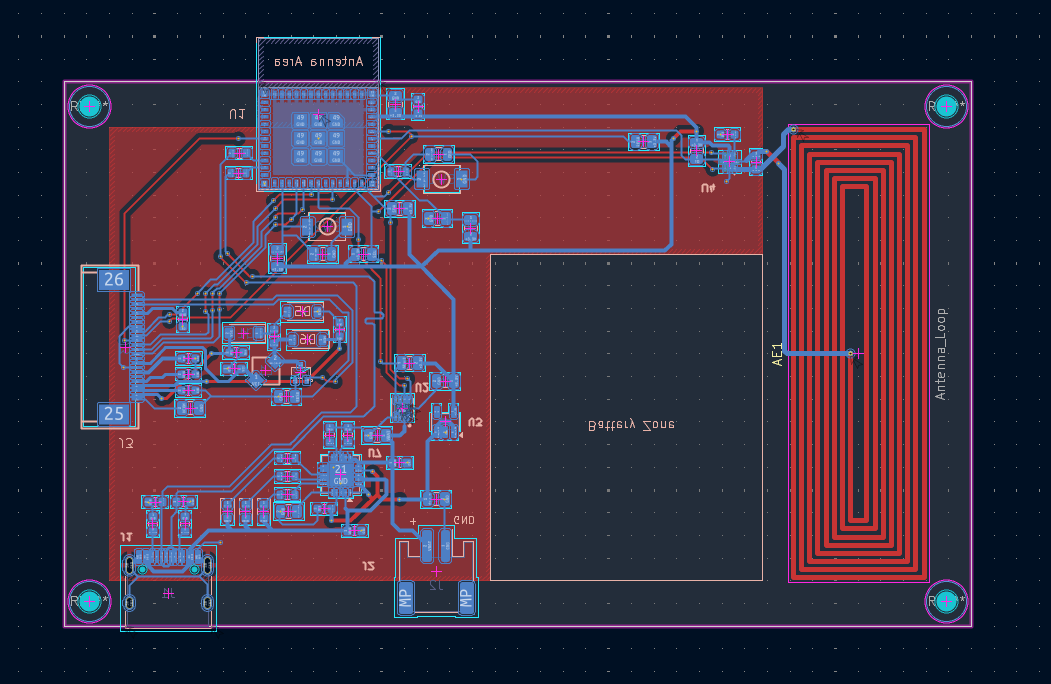
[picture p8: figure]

Figure 7: PCB layout showing the functional zone split: components and routing on the back copper (left two-thirds), the reserved battery zone, and the NFC antenna coil in its own strip on the right, with the ground pour kept clear of it on both layers. The ESP32-C3 module sits at the board edge with its antenna area overhanging.

### 6.4 Net classes and routing discipline

Class | Clearance | Track | Via/drill | Nets
Default | 0.2 | 0.25 | 0.6/0.3 | signals
Power | 0.2 | 0.4 | 0.6/0.3 | 3V3, VBUS, VBAT, VCI. . .
HV | 0.5 | 0.4 | 0.6/0.3 | VGH, VGL, VSH1/2, VSL
USB | 0.2 | 0.25 | 0.6/0.3 | D± pair (0.25/0.2 gap)

Table 6: Net classes (mm). All within JLCPCB standard capability — no fine-feature surcharge.

Routing order: power trunks → USB differential pair → boost switching loop (tight and fat) → NFC feed → HV rails → SPI → I

2C → remainder → pours and stitching → DRC. The D± pair measured 0.24 mm length mismatch worst-case — negligible at full-speed USB. Power trunks stay at 0.4 mm, necking only at fine-pitch pad entries.

## 7 Verification and Design Review

### 7.1 ERC and DRC

ERC closes clean apart from one documented informational note (VDDIO deliberately tied to VCI per SSD1680 §5). DRC progressed 38 → 12 → 0 violations across review passes, with 12 documented exclusions — each with a written justification, because an undocumented exclusion is indistinguishable from a suppressed defect. Representative examples: the MAX17048’s own 0.5 mm-pitch footprint violates the 0.2 mm clearance rule between its own pads (a property of the manufacturer’s land pattern, not the routing); the antenna coil “shorts” against its own feed pads because the spiral is graphic copper with no net; the module silk crosses the board edge because the antenna overhang is intentional.

### 7.2 Lessons worth keeping

- A net label on an unrouted pad looks identical to a connected one in a netlist check — trace actual copper for critical nets (found: two grounded FPC pads with no physical connection, including the BS1 mode strap without which the panel never communicates).
- Plausible, specific-sounding review claims still lose to primary sources (the 10 µH inductor challenge).
- Read electrical characteristics at your operating point, not the headline row (Rds(on), diode Vf , MLCC DC bias).
- Symbol pin mapping vs. package pinout is invisible to ERC — verify against the package drawing (the GSD MOSFET).
- Part-number metadata deserves the same rigor as copper: a final ref-by-ref audit of every LCSC field — value, package and variant against the placed footprint — caught substitutions (a wrong THERM resistor, a bottom-contact connector variant) that a copper-perfect design cannot reveal.

## 8 Manufacturing

Fabrication targets JLCPCB, 2-layer, with full SMT assembly (the 0.5 mm-pitch FPC connector should not be hand-soldered). Gerbers follow JLCPCB’s KiCad guide: Protel extensions, X2 attributes, netlist included, 4.6 mm format; drill files in Excellon. The BOM carries an LCSC Part # column and excludes DNP positions (the two ESD capacitor placeholders) and the etched antenna; the CPL (component placement list) gives each part’s centroid, side — all bottom — and rotation.

Pre-order checklist:
- Verify polarized-part orientation (Q2, U7, U2, U4, diodes, LEDs) in JLCPCB’s assembly preview — KiCad and JLCPCB rotation conventions disagree per-part, and the preview is where it shows.
- Nylon (not steel) M2 screws on the two mounting holes nearest the NFC coil, so hardware does not shift the antenna tuning.
- On battery arrival: verify lead polarity against J2 with a multimeter before first connection — JST-PH plug polarity is not universal, and reversal is destructive.

## 9 Firmware Notes and Future Work

- Display orientation: if the mounted panel renders upside down, it is a firmware fix (SSD1680 scan-direction / RAM entry-mode registers 0x01/0x11), not hardware.
- Temperature: use the SSD1680’s internal sensor (command 0x18, data 0x80); note it reads die temperature, so displayed ambient will read slightly high — a dedicated sensor is a rev-2 candidate.
- Flashing: native USB handles download mode automatically; BOOT+RESET is the guaranteed manual recovery path.
- NFC tuning: if read range is marginal, adjust C14 after measuring actual resonance.
- Rev 2 candidates: ESD/TVS protection on USB data for the sale version, ambient temperature sensor, expanded thermal via grid under the charger.

## Acknowledgements

This project was a collaboration between a human designer and an AI. Claude (Anthropic) acted as the senior-engineer reviewer this project would not otherwise have had: verifying every major decision against the primary datasheets, challenging design assumptions (and gracefully losing the arguments it deserved to lose), auditing the BOM before ordering — where it caught, among other things, the THERM resistor substitution that would have produced a card that never charges — writing the parametric generator that produced the NFC antenna footprint (tools/make nfc antenna.py → NFC Antenna 50x15 8T.kicad mod) in place of an error-prone hand-drawn spiral, and drafting the document you are reading. Without that guidance this project may well not have reached a manufacturable state. The design choices — and any mistakes that remain — are mine; several of the catches were not.

## A Toolchain and Library Setup

Steps to reproduce the design environment from a clean machine.

A.1 KiCad and the Espressif library

1. Install KiCad (https://www.kicad.org). This project was built across KiCad 9/10.
2. Download or clone Espressif’s official KiCad library: https://github.com/espressif/
| kicad-libraries. (https://github.com/espressif/kicad-libraries)
3. In KiCad: Preferences → Manage Symbol Libraries → Add, pointing at Espressif.kicad sym;
| then Preferences → Manage Footprint Libraries → Add, pointing at Espressif.pretty. Add the library’s 3d directory if you want module 3D models in the viewer.
A.2 | Importing LCSC/JLCPCB parts (easyeda2kicad)

Several footprints in this project (the easyeda2kicad: prefix — the FPC connector, inductor, MOSFET, switches) were generated directly from LCSC’s own part models rather than drawn

by hand:
1. pip install easyeda2kicad
2. easyeda2kicad --full --lcsc id=C262643 — symbol, footprint and 3D model in one command, per part.
3. Register the generated easyeda2kicad library once, the same way as above.

A.3 Fabrication exports

Two working options for JLCPCB production files:
- Fabrication Toolkit (install via Tools → Plugin and Content Manager ): one click pro-
| duces gerbers, BOM and CPL in JLCPCB format, reading each symbol’s LCSC field — see the README section on including component part numbers in production files: https: //github.com/bennymeg/Fabrication-Toolkit.
- Native KiCad, as used for this run: gerbers and drill per the export settings recorded in
| the change log; CPL via PCB editor → File → Fabrication Files → Component Placement; BOM via the schematic editor’s symbol-fields export — note the PCB-side BOM export does not include custom fields like LCSC. Remember to exclude the DNP rows (C5/C6) and the copper antenna (AE1) before upload.

The kicad-jlcpcb-tools plugin (https://github.com/Bouni/kicad-jlcpcb-tools/releases) additionally browses the JLCPCB parts database from inside KiCad, and parts can be reserved ahead of an order through the JLCPCB parts cart / private library (https://jlcpcb.com/user-center/smtPrivateLibrary/partsCart/). (https://jlcpcb.com/user-center/smtPrivateLibrary/partsCart/)

A.4 Analysis tools used in this design

- ST eDesign antenna calculator — coil geometry and inductance iteration: https:
| //eds.st.com/antenna/
- All About Circuits LC resonance calculator — resonant tank sanity checks: https:
| //www.allaboutcircuits.com/tools/lc-resonance-calculator/
- “Design Your Own NFC Antenna” — All on electronics (video walkthrough that
| informed the antenna approach): https://www.youtube.com/watch?v=j1Ck5NCs40M
- Samsung MLCC characteristics viewer — the DC-bias curves behind the VCOM
| capacitor verification: https://weblib.samsungsem.com/mlcc/mlcc-ec.do

## B Specification Sheet

ESP32-C3 e-paper NFC device — rev A — 2026-08-24. Values are marked [V] verified against a datasheet, layout file or CAD model, [E] estimated, or [TBC] to be confirmed on hardware.

B.1 | At a Glance
Function | E-paper display with NFC tap-to-share and Wi-Fi/BLE connectivity
Modes | Desk nameplate / event badge / tap-to-share card (firmware-selected)
Outer dimensions | 104.6 × 69.6 × 11.1 mm [V]
Mass, assembled | ≈ 68 g [E]
Power | 1S Li-Po, USB-C rechargeable
Enclosure | Two-part 3D print, M2 screws

Table 7: Device overview.

B.2 | Mechanical
B.2.1 | PCB
Outline | 100.0 × 60.0 mm [V]
Area | 6000 mm²

(60 cm²
)
Thickness | 1.6 mm [V]
Layers | 2 (F.Cu, B.Cu) [V]
Assembly | Single-sided — all components on B.Cu [V]
Mounting holes | 4 × Ø2.2 mm NPTH for M2, 2.75 mm in from each corner [V]
Copper features on F.Cu | NFC antenna coil only
Min track width | 0.25 mm signal / 0.40 mm power [V]
Min clearance | 0.20 mm (0.50 mm on HV class) [V]
Via / drill | 0.6 / 0.3 mm [V]
Surface finish | ENIG recommended
Placements | 59 across 27 orderable line items [V]

Table 8: PCB mechanical specification.

B.2.2 | Enclosure
Outer | 104.6 × 69.6 × 11.1 mm [V]
Wall thickness | 2.0 mm [V]
Floor thickness | 2.0 mm [V]
PCB fit clearance | 0.3 mm per side [V], may open to 0.4–0.5 mm [TBC]
Split line | z = +1.6 mm — tray below, cover above [V]
Internal cavity | 100.6 × 65.6 × 5.5 mm deep [V]
Board support | 4 × Ø4.5 mm bosses with Ø1.7 mm pilot holes [V]
Fasteners | 4 × M2 self-tapping; nylon in the two holes nearest the coil
Tray volume | 20 591 mm³ ≈ 25.5 g PLA at 100% infill [V]
Cover volume | 9 736 mm³ ≈ 12.1 g PLA at 100% infill [V]
USB-C opening | 12.6 × 6.2 mm [V]
Button access | 2 × Ø2.0 mm through the tray floor [V]

Table 9: Enclosure specification.

Case outline is 104.6 = board 100 + 0.3 clearance + 2.0 wall per side. The 69.6 dimension (rather than 64.6) accommodates the ESP32 module’s antenna, which overhangs the board edge by 4.72 mm by design.

B.2.3 | Stack-up
Layer | Thickness | z range
Front cover, panel recessed into it | 2.0 mm | +1.6 → +3.6
PCB | 1.6 mm | 0 → +1.6
Battery + clearance | 5.5 mm | 0 → −5.5
Tray floor | 2.0 mm | −5.5 → −7.5
Total | 11.1 mm

Table 10: Vertical stack-up.

B.3 | Display
Part | GDEM0266T71WT (Good Display)
Technology | E-paper, monochrome, bistable — zero power to hold an image
Controller | SSD1680 (Solomon Systech)
Diagonal | 2.66 in
Resolution | 152 × 296 px [V]
Active area | 30.704 × 60.088 mm [V]
Outline | 36.30 × 71.82 × 1.0 mm [V]
Interface | 4-wire SPI, BS1 strapped low [V]
Connector | 24-pin 0.5 mm FPC, 14 mm tail [V]
HV rails | Generated on board — VGH, VGL, VSH1/2, VSL, VCOM
Typical operating current | 4.5 mA [V]
Peak refresh current | 40 mA typ / 60 mA max [V]
Temperature sensing | SSD1680 internal sensor (command 0x18, data 0x80)
Operating temperature | [TBC] — e-paper is expected to be the limiting component

Table 11: Display specification.

The active area is offset 6.07 mm from centre along the long axis, away from the FPC — the enclosure aperture is positioned accordingly, not centred.

B.4 | Wireless
MCU module | ESP32-C3-MINI-1-N4 (Espressif), RF pre-certified
Core | 32-bit RISC-V single core
Flash | 4 MB
Wi-Fi | 802.11 b/g/n, 2.4 GHz
Bluetooth | BLE 5
Antenna (Wi-Fi/BLE) | Integrated module PCB antenna, overhanging the board edge per Espressif guidance [V]
USB | Native USB (GPIO18/19) — programming and debug, no UART bridge

Table 12: Wireless MCU specification.

B.4.1 | NFC
Tag IC | NT3H2111W0FHKH (NXP NTAG I²C plus)
Standard | NFC Forum Type 2, 13.56 MHz
Host interface | I²C
Antenna | Custom PCB coil on F.Cu — 8 turns, 0.6 mm trace, 0.3 mm gap [V]
Coil area | 15 × 50 mm [V]
Coil inductance | ≈ 1.93 µH [E] — two independent calculation methods agree
Chip capacitance | 50 pF [V] (datasheet §13.1)
Tuning capacitor | 22 pF C0G/NP0 [V]
Field-detect | FD → GPIO3, deep-sleep wake on tap [V]
Read range | [TBC] — measure after assembly; C14 is the tuning point

Table 13: NFC specification.

Chemistry | Lithium polymer, 1 cell
Capacity | 500 mAh (200–600 mAh range supported)
Nominal / max voltage | 3.7 V / 4.2 V
Cell | Uxney 503035, 35 × 30 × 5 mm, integrated protection
Connector | JST-PH 2.0 mm, S2B-PH-SM4-TB horizontal SMT [V]
Connector rating | 2 A, 100 V, −25 to +85 °C [V]
Retention | Printed rib frame, 0.5 mm clearance all round [V]

Table 14: Battery specification.

B.5 | Power
B.5.1 | Battery

Polarity is not standardised on JST-PH plugs — verify with a multimeter against J2 before first connection.

B.5.2 | Charging — MCP73871-2CC
Parameter | Value | Set by
Input | USB-C VBUS, 5 V
Regulation voltage | 4.20 V [V] | part suffix -2CC
Input current limit | 500 mA [V] | PROG2 → OUT
Charge current | ≈ 303 mA [E] | PROG1, 3.3 kΩ (Eq 5-1)
Termination current | ≈ 42 mA [E] | PROG3, 24 kΩ (Eq 4-2)
Safety timer | 6 h [V] | TE → GND
Low-battery threshold | 3.1 V [V] | part suffix -2CC
Thermal regulation | THERM held at 0.5 V by fixed 10 kΩ [V] | see note
Worst-case dissipation | ≈ 0.4W [E]
Topology | Power-path — system runs from USB when present, battery otherwise

Table 15: Charger configuration.

The battery pack has no accessible thermistor, so THERM is given a fixed 10 kΩ to VSS. The pin sources 50 µA, giving 0.5 V — between the 1.24 V cold and 0.25 V hot fault thresholds. Temperature protection is delegated to the pack’s own circuit.

B.5.3 | Regulation — AP2112K-3.3
Output | 3.3 V
Rated current | 600 mA min [V]
Input source | Charger SYS/OUT rail, not the battery terminal
Package | SOT-23-5
Decoupling | 1 µF in, 1 µF out

Table 16: LDO regulator specification.

B.5.4 | Fuel gauge — MAX17048
B.5.5 | Current Budget [E]

Battery life is not quoted — it depends entirely on refresh interval and radio duty cycle, and should be measured on hardware rather than predicted.

Method | ModelGauge — no sense resistor
Operating current | 3 µA [V]
Interface | I²C
Sense point | VBAT (VDD and CELL both on the raw cell) [V]
Alert | ALRT → GPIO4, deep-sleep wake [V]

Table 17: Fuel gauge specification.

State | Estimate | Note
Deep sleep | ≈ 10–20 µA | MCU deep sleep + gauge 3 µA + leakage
Display holding image | 0 µA | bistable — no power to retain
Display refresh | 40–60 mA for a few seconds | panel datasheet §6.2
Wi-Fi transmit | up to ∼350 mA peak | ESP32-C3 typical
NFC tap (harvested) | field-powered | tag responds without waking MCU

Table 18: Current budget by state.

B.6 | Interfaces and Controls
Item | Part | Notes
USB-C | HRO TYPE-C-31-M-12, 16P | USB 2.0, CC1/CC2 each 5.1 kΩ to GND
Battery | JST-PH S2B-PH-SM4-TB | horizontal SMT, silkscreen “+” marked
Display FPC | Jushuo AFC07-S24ECA-00 | 24P, 0.5 mm, top contact
Buttons | 2 × TS-1088-AR02016 | BOOT and RESET, 2.0 mm actuator, 1.6 N
Status LEDs | 3 × red 0603 | STAT1, STAT2, PG — lit only when USB present

Table 19: Interfaces and controls.

B.6.1 Pin Map

Wake sources are restricted to GPIO0–5, the RTC-capable range: GPIO3 for an NFC tap and GPIO4 for a low-battery alert.

B.7 Manufacturing

Pre-order checklist

- Verify polarised-part rotations (Q2, U7, U2, U4, diodes, LEDs) in the assembly preview
- Confirm the BOM excludes DNP rows and the etched antenna
- Dry-fit the FPC before printing the cover — the path has 0.07 mm of margin
B.8 | Environmental
B.9 | Open Items
1. FPC tail length has 0.07 mm of margin — dry-fit before committing to a print
2. Connector clearances rest on datasheet figures; J1, J2 and J3 have no 3D models
3. The 0.3 mm case fit clearance is untested on a real print
4. NFC read range unmeasured; C14 is the accessible tuning point
5. Board not yet fabricated

GPIO | Net | Note
0 | I2C SDA | shared bus — NFC + fuel gauge
1 | I2C SCL | shared bus
2 | EPD RST | strapping pin, 10 kΩ pull-up
3 | NFC FD | deep-sleep wake (RTC-capable)
4 | FUELGAUGE ALERT | deep-sleep wake (RTC-capable)
5 | EPD BUSY | input
6 | EPDCLK | e-paper SPI clock
7 | EPDDATA | e-paper SPI data
8 | STATUS LED | strapping, high at boot
9 | BOOT | strapping, pull-up + debounce
10 | EPD CS | chip select
18 / 19 | USB D− / D+ | 0 Ω series
20 | EPD DC | data/command
21 | UART0 TX | optional debug
EN | RESET | 10 kΩ pull-up + cap + button

Table 20: GPIO pin map.

Fabricator | JLCPCB
Process | 2-layer, full SMT assembly, single-sided
Design rules | Within standard capability — no fine-feature surcharge
DRC | 0 violations, 12 documented exclusions [V]
ERC | Clean apart from one intentional informational note [V]
Gerber set | 9 files, Protel extensions, X2 attributes
BOM | 27 line items, 59 placements, LCSC part numbers on every row [V]
DNP | C5, C6 — USB ESD positions, deliberately unpopulated
Not in BOM | AE1 — the antenna is etched copper
Enclosure | FDM, PLA, 2 parts, no supports required [TBC]

Table 21: Manufacturing summary.

Operating temperature | [TBC] — limited by the e-paper panel
Connector ratings | JST-PH −25 to +85 °C, USB-C −30 to +80 °C [V]
Battery | charge 0 to +45 °C typical for Li-Po [TBC]
Ingress protection | none

Table 22: Environmental ratings.

## C Full Bill of Materials

Designators | Value / Part | Package | LCSC
U1 | ESP32-C3-MINI-1-N4 | module | C2838502
U2 | MAX17048G+T10 | TDFN-8 + EP | C2682616
U3 | AP2112K-3.3 | SOT-23-5 | C51118
U4 | NT3H2111W0FHKH | XQFN-8 | C710403
U7 | MCP73871-2CC | QFN-20 + EP | C5121473
J1 | USB-C TYPE-C-31-M-12 | 16P | C165948
J2 | JST S2B-PH-SM4-TB | PH 2.0 horiz. | C295747
J3 | AFC07-S24ECA-00 | 24P 0.5 mm top-contact | C262643
Q2 | SI1304BDL | SOT-323 | C7419947
L1 | 47 µH CDRH2D18 | SMD | C2454210
D1, D5, D6 | MBR0530 | SOD-123 | C77336
D2, D3, D4 | Red LED | 0603 | C2286
SW1, SW2 | TS-1088-AR02016 | 4×3 mm | C720477
R2,R3,R8,R9,R12,R17–R19 | 10 kΩ | 0805 | C17414
R1, R4, R5 | 0 Ω | 0603 | C21189
R6, R7 | 5.1 kΩ | 0603 | C23186
R10 | 3.3 kΩ | 0603 | C22978
R11 | 24 kΩ | 0603 | C23352
R13, R14, R15 | 470 Ω | 0603 | C23179
R16 | 2.2 Ω | 0805 | C17521
C1, C3, C8, C24 | 100 nF | 0805 | C28233
C2, C11 | 10 µF | 0603 | C19702
C4, C9, C10, C18 | 1 µF 50 V X7R | 0805 | C28323
C7, C12 | 4.7 µF | 0603 | C19666
C13 | 220 nF | 0603 | C21120
C14 | 22 pF C0G | 0603 | C1653
C15–C17, C19–C23 | 1 µF 50 V X5R | 0603 | C15849
C5, C6 | DNP (ESD positions) | 0603 | —
AE1 | NFC coil (etched copper) | — | —

Table 23: Complete BOM, 27 orderable line items / 59 placements.

## D References

- Espressif, ESP32-C3-MINI-1 Datasheet — module dimensions, peripheral schematics, land pattern.
- Espressif, ESP32-C3 Hardware Design Guidelines — module antenna placement.
- Microchip, MCP73871 Datasheet + evaluation board layout — strap configuration, THERM behavior (§5.1.4), thermal practice.
- Analog Devices/Maxim, MAX17048/49 Datasheet — VDD/CELL sensing.
- NXP, NT3H2111/2211 Datasheet §13.1 + AN11276 — internal capacitance, antenna equivalent circuit.
- Dalian Good Display, GDEM0266T71WT Product Specification Rev 1.0 — §6.2 DC characteristics, §9 reference application circuit.
- Solomon Systech, SSD1680 Datasheet — §5 pin function, §6.3.1 interface select, command table.
- Sumida, CDRH2D18/LD Datasheet — inductor ratings.
- JST, PH Connector Datasheet — battery connector ratings.
- Design tools, plugins and calculators: see Appendix A.
- JLCPCB, Generating Gerber and drill files in KiCad — export configuration.

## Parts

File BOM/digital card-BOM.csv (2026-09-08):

Id | Designator | Footprint | Quantity | Designation | Supplier and ref
1 | AE1 | NFC_Antenna_50x15_8T | 1 | Antenna_Loop
2 | C1, C3, C8, C24 | C_0805_2012Metric | 4 | 0.1uF
3 | C2, C11 | C_0603_1608Metric | 2 | 10uF
4 | C4, C9, C10, C18 | C_0805_2012Metric | 4 | 1uF
5 | C5, C6 | C_0603_1608Metric | 2 | C
6 | C7, C12 | C_0603_1608Metric | 2 | 4.7uF
7 | C13 | C_0603_1608Metric | 1 | 220nF
8 | C14 | C_0603_1608Metric | 1 | 21pF
9 | C15, C16, C17, C19, C20, C21, C22, C23 | C_0603_1608Metric | 8 | 1uF
10 | D1, D5, D6 | D_SOD-123 | 3 | MBR0530
11 | D2, D3, D4 | LED_0603_1608Metric | 3 | LED
12 | J1 | USB_C_Receptacle_HRO_TYPE-C-31-M-12 | 1 | USB_C_Receptacle_USB2.0_16P
13 | J2 | JST_PH_S2B-PH-SM4-TB_1x02-1MP_P2.00mm_Horizontal | 1 | Conn_01x02_Pin
14 | J3 | FPC-SMD_AFC07-S24ECA-00 | 1 | Conn_01x24_Socket
15 | L1 | IND-SMD_L3.0-W3.0_CDRH2D18-HPNP | 1 | L
16 | Q2 | SOT-323-3_L2.0-W1.3-P1.30-LS2.1-BL | 1 | Q_NMOS_GSD
17 | R1, R4, R5 | R_0603_1608Metric | 3 | 0
18 | R2, R3, R8, R12, R17, R18, R19 | R_0805_2012Metric | 7 | 10k
19 | R6, R7 | R_0603_1608Metric | 2 | 5.1K
20 | R9 | R_0805_2012Metric | 1 | 10K
21 | R10 | R_0603_1608Metric | 1 | 3.3k
22 | R11 | R_0603_1608Metric | 1 | 24k
23 | R13, R14, R15 | R_0603_1608Metric | 3 | 470
24 | R16 | R_0805_2012Metric | 1 | 2.2
25 | SW1, SW2 | SW-SMD_L3.9-W3.0-P4.45 | 2 | SW_Push
26 | U1 | ESP32-C3-MINI-1 | 1 | ESP32-C3-MINI-1
27 | U2 | SON50P200X200X80-9N | 1 | MAX17048G_T10
28 | U3 | SOT-23-5 | 1 | AP2112K-3.3
29 | U4 | QFN8P50_160X160X50L40X20N | 1 | NT3H2111W0FHKH
30 | U7 | QFN-20-1EP_4x4mm_P0.5mm_EP2.5x2.5mm | 1 | MCP73871-2CC

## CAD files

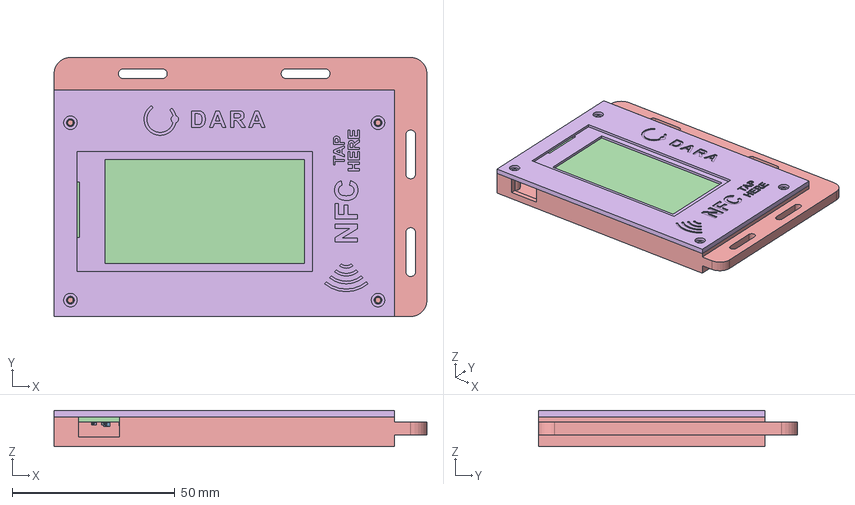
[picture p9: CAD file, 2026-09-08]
Case/Digital_Card_Case_3_BADGE.FCStd
114.6 x 79.6 x 11.1 mm
C_0603_1608Metric
R_0603_1608Metric
R_0603_1608Metric001
C_0603_1608Metric001
LED_0603_1608Metric
C_0805_2012Metric
R_0805_2012Metric
R_0603_1608Metric002
R_0805_2012Metric001
R_0603_1608Metric003
C_0603_1608Metric002
LED_0603_1608Metric001
R_0805_2012Metric002
R_0805_2012Metric003
C_0603_1608Metric003
QFN-20-1EP_4x4mm_P0.5mm_EP2.5x2.5mm
C_0603_1608Metric004
C_0603_1608Metric005
C_0805_2012Metric001
C_0603_1608Metric006
C_0805_2012Metric002
D_SOD-123
C_0603_1608Metric007
R_0805_2012Metric004
R_0603_1608Metric004
C_0805_2012Metric003
R_0805_2012Metric005
C_0603_1608Metric008
LED_0603_1608Metric002
C_0603_1608Metric009
R_0603_1608Metric005
R_0805_2012Metric006
C_0805_2012Metric004
R_0603_1608Metric006
C_0805_2012Metric005
C_0603_1608Metric010
C_0603_1608Metric011
D_SOD-124
DFN1006.STEP^DFN1006.STEP_Submodel-SOD882_part_DesignRootModel_PCB_ESP32-C3-MINI-1_V1(2)_PCB_ESP32-C3-MINI-1_V1
R0201_20210301.STEP^R0201_20210301.STEP_Submodel-R0201_part_DesignRootModel_PCB_ESP32-C3-MINI-1_V1(2)_PCB_ESP32-C3-MINI-1_V1
R0201_20210301.STEP^R0201_20210301.STEP_Submodel-R0201_part_DesignRootModel_PCB_ESP32-C3-MINI-1_V1(2)_PCB_ESP32-C3-MINI-1_V001
R0201_20210301.STEP^R0201_20210301.STEP_Submodel-R0201_part_DesignRootModel_PCB_ESP32-C3-MINI-1_V1(2)_PCB_ESP32-C3-MINI-1_V002
placementOutline^Submodel-noModelForPart_MINI-ANT-TYPED-H_1968823293_Submodel-MINI-ANT-TYPED-H_1968823293_part_DesignRootModel_PCB_ESP32-C3-MINI-1_V1(2)_PCB_ESP
placementOutline-0^Submodel-noModelForPart_MINI-ANT-TYPED-H_1968823293_Submodel-MINI-ANT-TYPED-H_1968823293_part_DesignRootModel_PCB_ESP32-C3-MINI-1_V1(2)_PCB_E
placementOutline-1^Submodel-noModelForPart_MINI-ANT-TYPED-H_1968823293_Submodel-MINI-ANT-TYPED-H_1968823293_part_DesignRootModel_PCB_ESP32-C3-MINI-1_V1(2)_PCB_E
placementOutline-2^Submodel-noModelForPart_MINI-ANT-TYPED-H_1968823293_Submodel-MINI-ANT-TYPED-H_1968823293_part_DesignRootModel_PCB_ESP32-C3-MINI-1_V1(2)_PCB_E
placementOutline-3^Submodel-noModelForPart_MINI-ANT-TYPED-H_1968823293_Submodel-MINI-ANT-TYPED-H_1968823293_part_DesignRootModel_PCB_ESP32-C3-MINI-1_V1(2)_PCB_E
placementOutline-4^Submodel-noModelForPart_MINI-ANT-TYPED-H_1968823293_Submodel-MINI-ANT-TYPED-H_1968823293_part_DesignRootModel_PCB_ESP32-C3-MINI-1_V1(2)_PCB_E
placementOutline-5^Submodel-noModelForPart_MINI-ANT-TYPED-H_1968823293_Submodel-MINI-ANT-TYPED-H_1968823293_part_DesignRootModel_PCB_ESP32-C3-MINI-1_V1(2)_PCB_E
trace_4^Submodel-MINI-ANT-TYPED-H_1968823293_part_DesignRootModel_PCB_ESP32-C3-MINI-1_V1(2)_PCB_ESP32-C3-MINI-1_V1
trace_1^Submodel-MINI-ANT-TYPED-H_1968823293_part_DesignRootModel_PCB_ESP32-C3-MINI-1_V1(2)_PCB_ESP32-C3-MINI-1_V1
C0402_20210301.STEP^C0402_20210301.STEP_Submodel-C0402_part_DesignRootModel_PCB_ESP32-C3-MINI-1_V1(2)_PCB_ESP32-C3-MINI-1_V1
R0201_20210301.STEP^R0201_20210301.STEP_Submodel-R0201_part_DesignRootModel_PCB_ESP32-C3-MINI-1_V1(2)_PCB_ESP32-C3-MINI-1_V004
R0201_20210301.STEP^R0201_20210301.STEP_Submodel-R0201_part_DesignRootModel_PCB_ESP32-C3-MINI-1_V1(2)_PCB_ESP32-C3-MINI-1_V005
R0201_20210301.STEP^R0201_20210301.STEP_Submodel-R0201_part_DesignRootModel_PCB_ESP32-C3-MINI-1_V1(2)_PCB_ESP32-C3-MINI-1_V006
C0201_20210301.STEP^C0201_20210301.STEP_Submodel-C0201_part_DesignRootModel_PCB_ESP32-C3-MINI-1_V1(2)_PCB_ESP32-C3-MINI-1_V1
R0201_20210301.STEP^R0201_20210301.STEP_Submodel-R0201_part_DesignRootModel_PCB_ESP32-C3-MINI-1_V1(2)_PCB_ESP32-C3-MINI-1_V008
R0201_20210301.STEP^R0201_20210301.STEP_Submodel-R0201_part_DesignRootModel_PCB_ESP32-C3-MINI-1_V1(2)_PCB_ESP32-C3-MINI-1_V009
R0201_20210301.STEP^R0201_20210301.STEP_Submodel-R0201_part_DesignRootModel_PCB_ESP32-C3-MINI-1_V1(2)_PCB_ESP32-C3-MINI-1_V010
C0201_20210301.STEP^C0201_20210301.STEP_Submodel-C0201_part_DesignRootModel_PCB_ESP32-C3-MINI-1_V1(2)_PCB_ESP32-C3-MINI-1_V001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

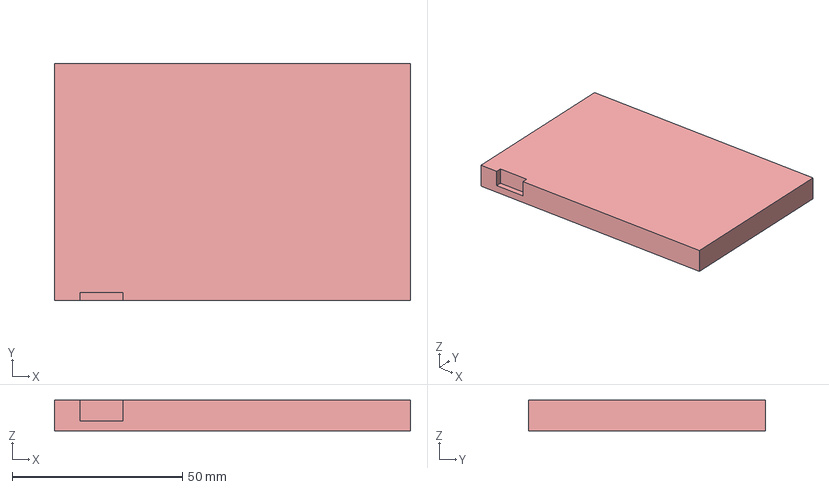
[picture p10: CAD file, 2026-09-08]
Case/Digital_Card_Case.backup-20260820.FCStd
104.6 x 69.6 x 9.10 mm
C_0603_1608Metric
R_0603_1608Metric
R_0603_1608Metric001
C_0603_1608Metric001
LED_0603_1608Metric
C_0805_2012Metric
R_0805_2012Metric
R_0603_1608Metric002
R_0805_2012Metric001
R_0603_1608Metric003
C_0603_1608Metric002
LED_0603_1608Metric001
R_0805_2012Metric002
R_0805_2012Metric003
C_0603_1608Metric003
QFN-20-1EP_4x4mm_P0.5mm_EP2.5x2.5mm
C_0603_1608Metric004
C_0603_1608Metric005
C_0805_2012Metric001
C_0603_1608Metric006
C_0805_2012Metric002
D_SOD-123
C_0603_1608Metric007
R_0805_2012Metric004
R_0603_1608Metric004
C_0805_2012Metric003
R_0805_2012Metric005
C_0603_1608Metric008
LED_0603_1608Metric002
C_0603_1608Metric009
R_0603_1608Metric005
R_0805_2012Metric006
C_0805_2012Metric004
R_0603_1608Metric006
C_0805_2012Metric005
C_0603_1608Metric010
C_0603_1608Metric011
D_SOD-124
DFN1006.STEP^DFN1006.STEP_Submodel-SOD882_part_DesignRootModel_PCB_ESP32-C3-MINI-1_V1(2)_PCB_ESP32-C3-MINI-1_V1
R0201_20210301.STEP^R0201_20210301.STEP_Submodel-R0201_part_DesignRootModel_PCB_ESP32-C3-MINI-1_V1(2)_PCB_ESP32-C3-MINI-1_V1
R0201_20210301.STEP^R0201_20210301.STEP_Submodel-R0201_part_DesignRootModel_PCB_ESP32-C3-MINI-1_V1(2)_PCB_ESP32-C3-MINI-1_V001
R0201_20210301.STEP^R0201_20210301.STEP_Submodel-R0201_part_DesignRootModel_PCB_ESP32-C3-MINI-1_V1(2)_PCB_ESP32-C3-MINI-1_V002
placementOutline^Submodel-noModelForPart_MINI-ANT-TYPED-H_1968823293_Submodel-MINI-ANT-TYPED-H_1968823293_part_DesignRootModel_PCB_ESP32-C3-MINI-1_V1(2)_PCB_ESP
placementOutline-0^Submodel-noModelForPart_MINI-ANT-TYPED-H_1968823293_Submodel-MINI-ANT-TYPED-H_1968823293_part_DesignRootModel_PCB_ESP32-C3-MINI-1_V1(2)_PCB_E
placementOutline-1^Submodel-noModelForPart_MINI-ANT-TYPED-H_1968823293_Submodel-MINI-ANT-TYPED-H_1968823293_part_DesignRootModel_PCB_ESP32-C3-MINI-1_V1(2)_PCB_E
placementOutline-2^Submodel-noModelForPart_MINI-ANT-TYPED-H_1968823293_Submodel-MINI-ANT-TYPED-H_1968823293_part_DesignRootModel_PCB_ESP32-C3-MINI-1_V1(2)_PCB_E
placementOutline-3^Submodel-noModelForPart_MINI-ANT-TYPED-H_1968823293_Submodel-MINI-ANT-TYPED-H_1968823293_part_DesignRootModel_PCB_ESP32-C3-MINI-1_V1(2)_PCB_E
placementOutline-4^Submodel-noModelForPart_MINI-ANT-TYPED-H_1968823293_Submodel-MINI-ANT-TYPED-H_1968823293_part_DesignRootModel_PCB_ESP32-C3-MINI-1_V1(2)_PCB_E
placementOutline-5^Submodel-noModelForPart_MINI-ANT-TYPED-H_1968823293_Submodel-MINI-ANT-TYPED-H_1968823293_part_DesignRootModel_PCB_ESP32-C3-MINI-1_V1(2)_PCB_E
trace_4^Submodel-MINI-ANT-TYPED-H_1968823293_part_DesignRootModel_PCB_ESP32-C3-MINI-1_V1(2)_PCB_ESP32-C3-MINI-1_V1
trace_1^Submodel-MINI-ANT-TYPED-H_1968823293_part_DesignRootModel_PCB_ESP32-C3-MINI-1_V1(2)_PCB_ESP32-C3-MINI-1_V1
C0402_20210301.STEP^C0402_20210301.STEP_Submodel-C0402_part_DesignRootModel_PCB_ESP32-C3-MINI-1_V1(2)_PCB_ESP32-C3-MINI-1_V1
R0201_20210301.STEP^R0201_20210301.STEP_Submodel-R0201_part_DesignRootModel_PCB_ESP32-C3-MINI-1_V1(2)_PCB_ESP32-C3-MINI-1_V004
R0201_20210301.STEP^R0201_20210301.STEP_Submodel-R0201_part_DesignRootModel_PCB_ESP32-C3-MINI-1_V1(2)_PCB_ESP32-C3-MINI-1_V005
R0201_20210301.STEP^R0201_20210301.STEP_Submodel-R0201_part_DesignRootModel_PCB_ESP32-C3-MINI-1_V1(2)_PCB_ESP32-C3-MINI-1_V006
C0201_20210301.STEP^C0201_20210301.STEP_Submodel-C0201_part_DesignRootModel_PCB_ESP32-C3-MINI-1_V1(2)_PCB_ESP32-C3-MINI-1_V1
R0201_20210301.STEP^R0201_20210301.STEP_Submodel-R0201_part_DesignRootModel_PCB_ESP32-C3-MINI-1_V1(2)_PCB_ESP32-C3-MINI-1_V008
R0201_20210301.STEP^R0201_20210301.STEP_Submodel-R0201_part_DesignRootModel_PCB_ESP32-C3-MINI-1_V1(2)_PCB_ESP32-C3-MINI-1_V009
R0201_20210301.STEP^R0201_20210301.STEP_Submodel-R0201_part_DesignRootModel_PCB_ESP32-C3-MINI-1_V1(2)_PCB_ESP32-C3-MINI-1_V010
C0201_20210301.STEP^C0201_20210301.STEP_Submodel-C0201_part_DesignRootModel_PCB_ESP32-C3-MINI-1_V1(2)_PCB_ESP32-C3-MINI-1_V001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

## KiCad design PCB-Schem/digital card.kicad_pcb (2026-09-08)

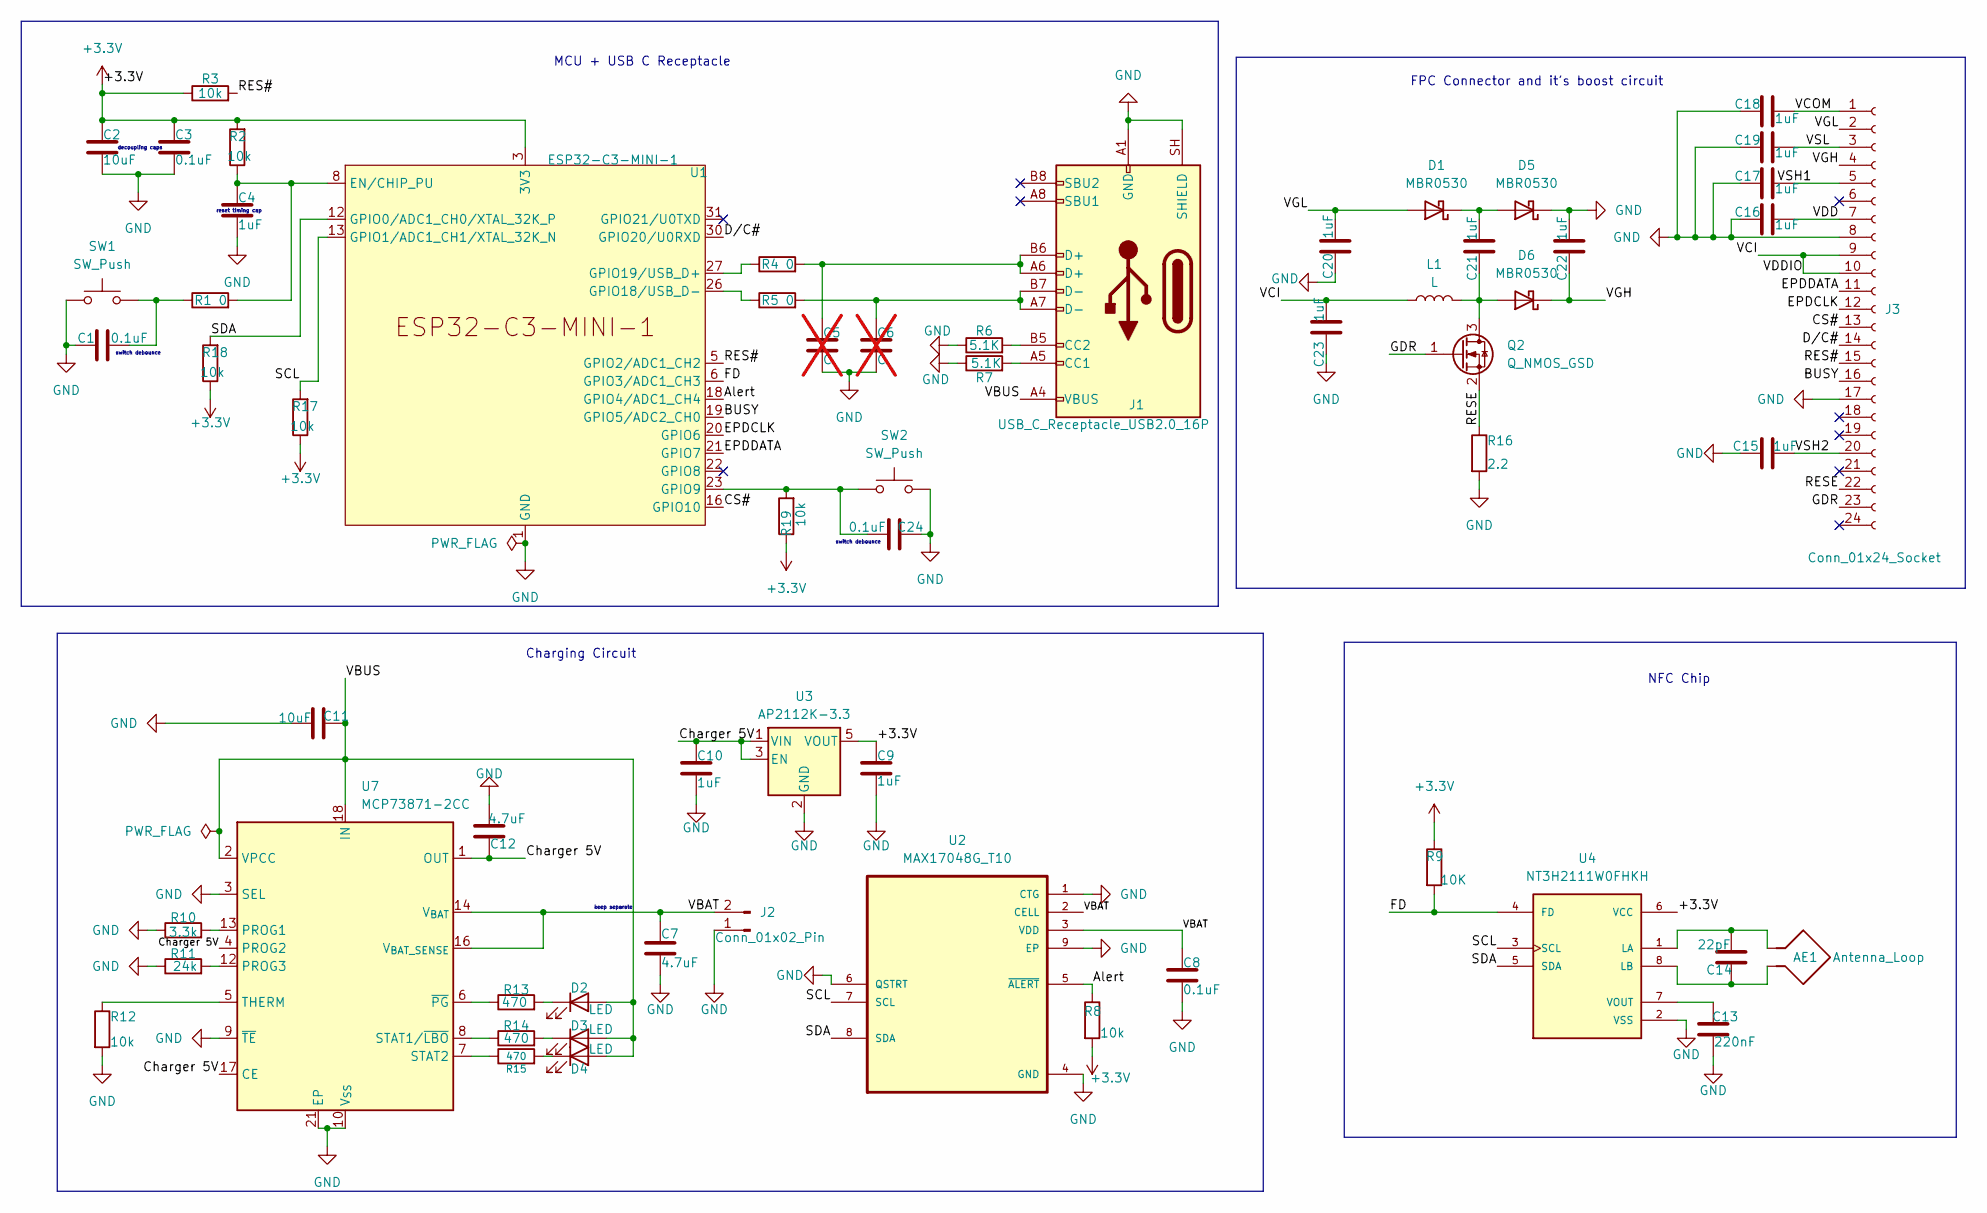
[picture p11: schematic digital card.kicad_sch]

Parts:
AE1: Antenna_Loop; NFC_Antenna_50x15_8T
C1, C3, C8, C24: 0.1uF; C_0805_2012Metric; LCSC C28233
C2, C11: 10uF; C_0603_1608Metric; LCSC C19702
C4, C9, C10, C18: 1uF; C_0805_2012Metric; LCSC C28323
C5, C6: C; C_0603_1608Metric; not fitted
C7, C12: 4.7uF; C_0603_1608Metric; LCSC C19666
C13: 220nF; C_0603_1608Metric; LCSC C21120
C14: 22pF; C_0603_1608Metric; LCSC C1653
C15, C16, C17, C19, C20, C21, C22, C23: 1uF; C_0603_1608Metric; LCSC C15849
D1, D5, D6: MBR0530; D_SOD-123; LCSC C77336
D2, D3, D4: LED; LED_0603_1608Metric; LCSC C2286
J1: USB_C_Receptacle_USB2.0_16P; USB_C_Receptacle_HRO_TYPE-C-31-M-12; LCSC C165948
J2: Conn_01x02_Pin; JST_PH_S2B-PH-SM4-TB_1x02-1MP_P2.00mm_Horizontal; LCSC C295747
J3: Conn_01x24_Socket; FPC-SMD_AFC07-S24ECA-00; LCSC C262643
L1: L; IND-SMD_L3.0-W3.0_CDRH2D18-HPNP; LCSC C2454210
Q2: Q_NMOS_GSD; SOT-323-3_L2.0-W1.3-P1.30-LS2.1-BL; LCSC C7419947
R1, R4, R5: 0; R_0603_1608Metric; LCSC C21189
R2, R3, R8, R12, R17, R18, R19: 10k; R_0805_2012Metric; LCSC C17414
R6, R7: 5.1K; R_0603_1608Metric; LCSC C23186
R9: 10K; R_0805_2012Metric; LCSC C17414
R10: 3.3k; R_0603_1608Metric; LCSC C22978
R11: 24k; R_0603_1608Metric; LCSC C23352
R13, R14, R15: 470; R_0603_1608Metric; LCSC C23179
R16: 2.2; R_0805_2012Metric; LCSC C17521
SW1, SW2: SW_Push; SW-SMD_L3.9-W3.0-P4.45; LCSC C720477
U1: ESP32-C3-MINI-1; LCSC C2838502
U2: MAX17048G_T10; SON50P200X200X80-9N; LCSC C2682616
U3: AP2112K-3.3; SOT-23-5; LCSC C51118
U4: NT3H2111W0FHKH; QFN8P50_160X160X50L40X20N; DigiKey_Part_Number 568-12900-1-ND
U7: MCP73871-2CC; QFN-20-1EP_4x4mm_P0.5mm_EP2.5x2.5mm; LCSC C5121473

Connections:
+3.3V: C2.1, C3.1, C9.1, R2.2, R3.1, R8.2, R9.1, R17.1, R18.1, R19.1, U1.3 (3V3), U3.5 (VOUT), U4.6 (VCC)
/Alert: R8.1, U1.18 (GPIO4/ADC1_CH4), U2.5 (~ALERT)
/BUSY: J3.16, U1.19 (GPIO5/ADC2_CH0)
/CS#: J3.13, U1.16 (GPIO10)
/Charger 5V: C10.1, C12.2, U3.1 (VIN), U3.3 (EN), U7.1 (OUT), U7.4 (PROG2), U7.17 (CE), U7.20 (OUT)
/D/C#: J3.14, U1.30 (GPIO20/U0RXD)
/EPDCLK: J3.12, U1.20 (GPIO6)
/EPDDATA: J3.11, U1.21 (GPIO7)
/FD: R9.2, U1.6 (GPIO3/ADC1_CH3), U4.4 (FD)
/GDR: J3.23, Q2.1 (G)
/RES#: J3.15, R3.2, U1.5 (GPIO2/ADC1_CH2)
/RESE: J3.22, Q2.2 (S), R16.1
/SCL: R17.2, U1.13 (GPIO1/ADC1_CH1/XTAL_32K_N), U2.7 (SCL), U4.3 (SCL)
/SDA: R18.2, U1.12 (GPIO0/ADC1_CH0/XTAL_32K_P), U2.8 (SDA), U4.5 (SDA)
/VBAT: C7.1, C8.1, J2.2, U2.2 (CELL), U2.3 (VDD), U7.14 (V_{BAT}), U7.15 (V_{BAT}), U7.16 (V_{BAT_SENSE})
/VBUS: C11.1, D2.2 (A), D3.2 (A), D4.2 (A), J1.A4 (VBUS), J1.A9 (VBUS), J1.B4 (VBUS), J1.B9 (VBUS), U7.2 (VPCC), U7.18 (IN), U7.19 (IN)
/VCI: C23.2, J3.9, J3.10, L1.1
/VCOM: C18.2, J3.1
/VDD: C16.2, J3.7
/VGH: C22.1, D6.1 (K), J3.4
/VGL: C20.2, D1.2 (A), J3.2
/VSH1: C17.2, J3.5
/VSH2: C15.2, J3.20
/VSL: C19.2, J3.3
GND: C1.1, C2.2, C3.2, C4.2, C5.2, C6.2, C7.2, C8.2, C9.2, C10.2, C11.2, C12.1, C13.2, C15.1, C16.1, C17.1, C18.1, C19.1, C20.1, C22.2, C23.1, C24.1, D5.1 (K), J1.A1 (GND), J1.A12 (GND), J1.B1 (GND), J1.B12 (GND), J1.SH (SHIELD), J2.1, J3.8, J3.17, R6.1, R7.1, R10.1, R11.1, R12.2, R16.2, SW1.1, SW2.1, U1.1 (GND), U1.2 (GND), U1.11 (GND), U1.14 (GND), U1.36 (GND), U1.37 (GND), U1.38 (GND), U1.39 (GND), U1.40 (GND), U1.41 (GND), U1.42 (GND), U1.43 (GND), U1.44 (GND), U1.45 (GND), U1.46 (GND), U1.47 (GND), U1.48 (GND), U1.49 (GND), U1.50 (GND), U1.51 (GND), U1.52 (GND), U1.53 (GND), U2.1 (CTG), U2.4 (GND), U2.6 (QSTRT), U2.9 (EP), U3.2 (GND), U4.2 (VSS), U7.3 (SEL), U7.9 (~TE), U7.10 (V_{SS}), U7.11 (V_{SS}), U7.21 (EP)
unnamed: C1.2, R1.1, SW1.2
unnamed: C5.1, J1.A6 (D+), J1.B6 (D+), R4.2
unnamed: C6.1, J1.A7 (D-), J1.B7 (D-), R5.2
unnamed: C21.2, D1.1 (K), D5.2 (A)
unnamed: D2.1 (K), R13.2
unnamed: D3.1 (K), R14.2
unnamed: D4.1 (K), R15.2
unnamed: C21.1, D6.2 (A), L1.2, Q2.3 (D)
unnamed: J1.A5 (CC1), R7.2
unnamed: J1.B5 (CC2), R6.2
unnamed: C4.1, R1.2, R2.1, U1.8 (EN/CHIP_PU)
unnamed: C24.2, R19.2, SW2.2, U1.23 (GPIO9)
unnamed: R5.1, U1.26 (GPIO18/USB_D-)
unnamed: R4.1, U1.27 (GPIO19/USB_D+)
unnamed: AE1.1, C14.2, U4.1 (LA)
unnamed: AE1.2, C14.1, U4.8 (LB)
unnamed: C13.1, U4.7 (VOUT)
unnamed: R10.2, U7.13 (PROG1)
unnamed: R11.2, U7.12 (PROG3)
unnamed: R14.1, U7.8 (STAT1/~LBO)
unnamed: R15.1, U7.7 (STAT2)
unnamed: R12.1, U7.5 (THERM)
unnamed: R13.1, U7.6 (~PG)

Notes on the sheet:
decoupling caps
MCU + USB C Receptacle
reset timing cap
switch debounce
Charging Circuit
FPC Connector and it's boost circuit
NFC Chip
keep separate

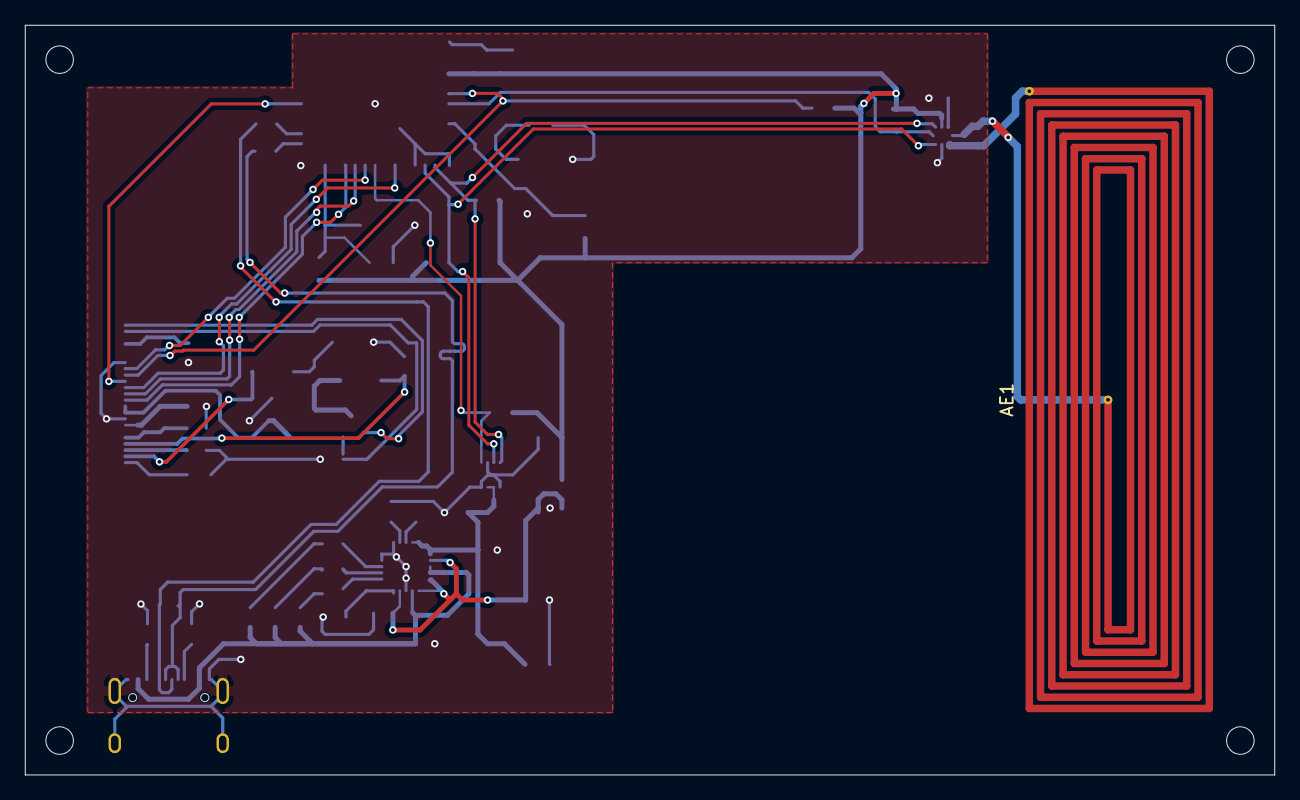
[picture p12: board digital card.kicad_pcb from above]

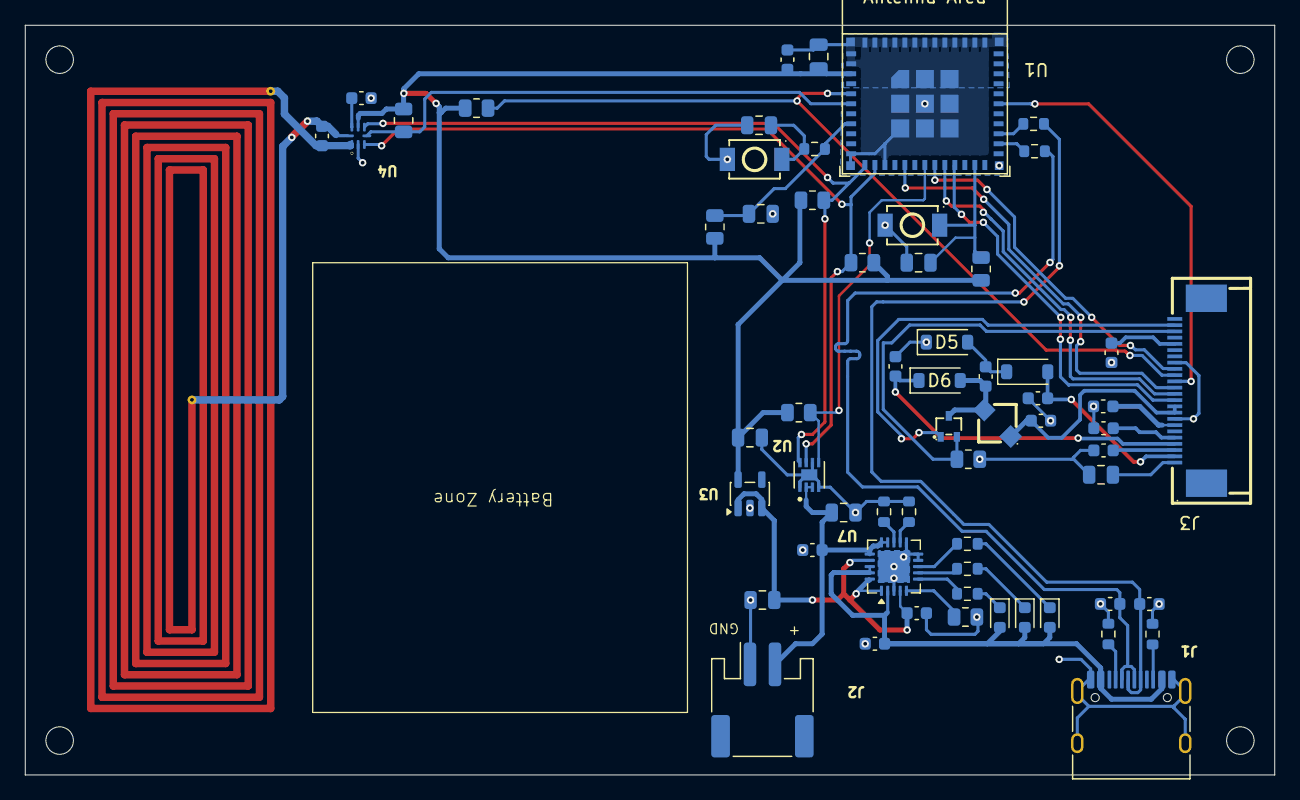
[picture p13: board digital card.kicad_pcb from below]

Board: 2 copper layers, 100.0 x 60.0 mm, 62 parts (61 on the bottom side), 48 nets.

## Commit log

2026-09-08 Add 'estimate:' prefix to mass values in README
    Updated mass estimates for various device components in the README.
2026-09-08 Update README with BOM and datasheet/spec sheet references
2026-09-08 docs: update README with full inline BOM table and spec-sheet index
2026-09-08 docs: fix BOM LCSC numbers and add full spec sheet from project report
